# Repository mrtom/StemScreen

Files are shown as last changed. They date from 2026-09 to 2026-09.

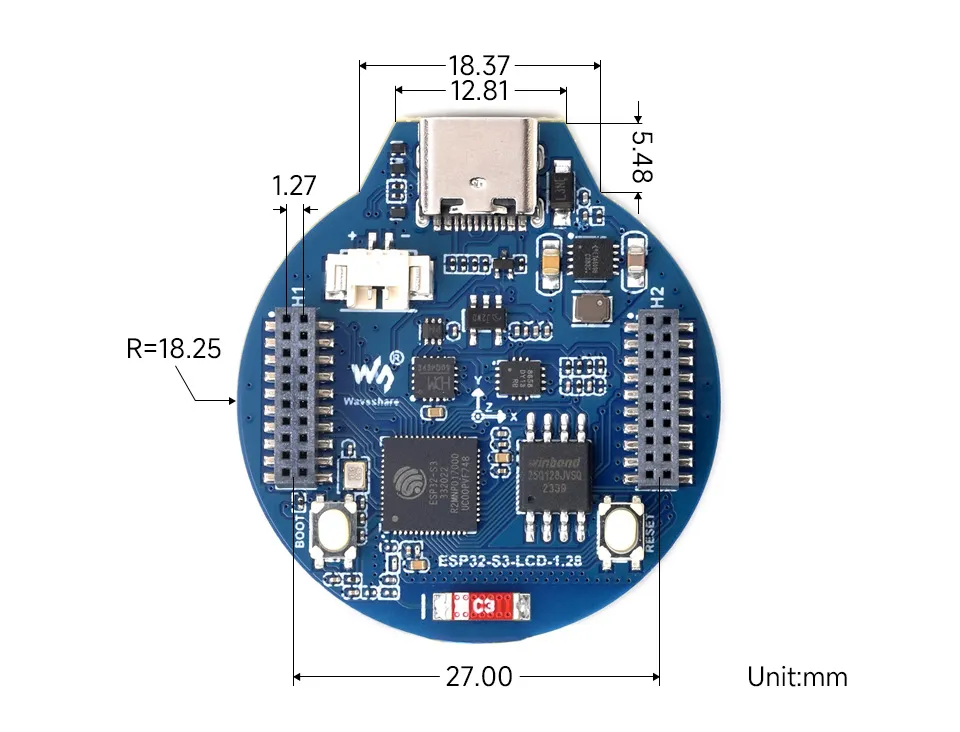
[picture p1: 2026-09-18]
CaseDesign/enclosure-v01/reference/waveshare-dimensions.webp

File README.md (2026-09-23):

# Bike Stem Computer — first Bluetooth test

## Display flicker fix (23 September 2026)

Text rectangles previously overwrote sections of the rings with black before
redrawing them, and the battery icon was cleared directly on the LCD. The new
renderer composes all layers in a 240×48 RAM buffer and sends each completed
band to the display. Unchanged screen/battery images are skipped. The buffer
uses 23,040 bytes (3,456 more than before); no full-screen allocation is needed.
The intended paused-status flash remains. Layout, battery levels and protocol
are unchanged. This addresses a concrete redraw issue; physical confirmation
that it resolves the reported flicker is pending.

Upload `StemScreen/StemScreen.ino` with the existing settings; no Garmin update
is needed. Check both pages for 30 seconds while running, including page rotation,
then pause: only the inner status ring should intentionally flash. The battery
icon and text should remain steady. If flicker persists, note the exact area and
whether it coincides with second ticks, page changes or pause flashing. Compare
USB-powered and battery-only operation with the same activity state. Flicker only
during updates suggests display scan/transfer tearing; whole-display brightness
changes or resets warrant a power/backlight investigation. Neither alternative
is established by the current report.

## Battery ring (22 September 2026)

The receiver now samples GPIO1 (`BAT_ADC`) with `analogReadMilliVolts()`: 16
readings spaced at least 10 ms apart, followed by a five-second interval. Sampling,
drawing and logging run outside BLE callbacks. `StemScreen/Battery.h` contains
the divider factor and the approximate LiPo interpolation curve (3.45 V empty,
4.20 V full). This is a voltage estimate, not a fuel gauge or runtime prediction.
Load, temperature and USB charging affect the estimate; 500 mAh does not change
the voltage curve.

Both rings are four pixels thick, separated by a two-pixel gap. A small battery
outline is centred on the battery ring at 12 o'clock on both pages, with two
pixels of black padding around it, and uses the battery ring colour. The icon is
empty at low, quarter/half/three-quarter filled at 25/50/75%, and solid at 100%.
Its fill uses the same stable level as the ring; invalid readings show an empty
grey icon. The outer battery ring appears outside the connection ring.
It fills clockwise from 12 o'clock, with small gaps at the quarter boundaries:

| Estimated charge | Outer ring |
| --- | --- |
| Below 25% | Short 15-degree red arc (low) |
| 25–49% | One quarter |
| 50–74% | Two quarters |
| 75–99% | Three quarters |
| 100% | Four quarters |

Non-low segments use the steady connection/activity tint, independent of paused
activity flashing. A two-percentage-point falling margin prevents rapid changes
at quarter boundaries. Invalid voltage or startup before sampling gives a grey
outline instead of a misleading full battery.

**Charging animation is implemented but not enabled on this board.** The
[non-touch schematic](https://files.waveshare.com/wiki/ESP32-S3-LCD-1.28/Esp32-s3-lcd-.128-sch.pdf)
does not show a charger-status or USB-present GPIO connection to the ESP32.
Firmware therefore reports `power=unknown`; high/rising voltage and an open
Serial Monitor are not charging detectors. A future reliable power-status input
can select `BatteryPower::Charging`: solid charge segments plus the next quarter
flashing every 500 ms, red below 25%, blue from 25% to below 100%, and the whole
ring flashing green at 100%. No hardware modification is part of this change.

**Verify the divider before relying on the ring.** Waveshare's
[current documentation](https://docs.waveshare.com/ESP32-S3-LCD-1.28) specifies
200 kΩ/100 kΩ (×3), whereas its linked schematic labels R4/R7 as 100 kΩ/100 kΩ
(×2). The implementation follows the requested ×3, exposed as `BATTERY_DIVIDER`.
ADC attenuation is 11 dB to accommodate either input range. Converted readings
outside 2.5–4.35 V are treated as invalid, not clamped to a full battery.

Upload `StemScreen/StemScreen.ino` using the existing ESP32S3/16MB/QSPI PSRAM
settings. This change needs no Garmin update if protocol v3 is already installed.
Open Serial Monitor at **115200 baud** and record `BAT t=... adc_mV=...
battery_mV=... approx_pct=... quarters=... valid=... power=unknown` lines.
Compare the connector voltage measured with a meter against `adc_mV` before
adjusting `BATTERY_DIVIDER`; record whether USB was connected. Check the ring on
both pages and during Garmin pause/stale/disconnected states. For a real discharge
runtime test, unplug USB-C (which supplies power/charges the cell), note start/end
times and ring transitions. USB serial logging itself changes the power conditions;
a battery-only serial capture needs an independently powered 3.3 V UART receiver
connected to board TX/GND only, with no power feed to the board. Do not infer
battery-only runtime from a USB-connected log. Physical calibration and runtime
validation are still pending.

Host battery checks:

```sh
c++ -std=c++11 -Wall -Wextra -Werror -pedantic tests/battery_test.cpp -o /tmp/stem-battery-test
/tmp/stem-battery-test
```

## Current display colours (22 September 2026)

The current clock/ride-time UI uses blue for fresh Garmin data with no activity
(or unknown activity state), and green for a confirmed activity. Running is steady
green; manual pause and Auto Pause flash the circumference ring green for 0.5 seconds,
then black for 0.5 seconds. The connection text and selected page dot share the
status colour but do not flash. Cyan means connected and awaiting data, orange
means no valid packet for five seconds, and red means disconnected. These link
warnings override activity colours and flashing. Time and detail text stay white
with fresh data and grey otherwise.

While running, a continuous local millisecond timer drives the ride display.
Garmin packets include fractional milliseconds. Packet arrivals preserve the local
phase: differences up to 150 ms are ignored; three consecutive larger differences
in the same direction trigger gradual correction at at most 1% of timer speed.
Pause/resume, timer resets, reconnection, recovery after stale data and differences
of at least two seconds resynchronise immediately. The number redraws as soon as
the main loop observes its next second, without waiting for the 250 ms UI refresh.
Paused, inactive or unknown activity states do not advance. Stale (five seconds),
disconnected and awaiting-data states show the last confirmed duration in grey.
BLE delivery delay is not measured, so this is a smooth estimate between samples.

**Update both devices for protocol v3.** Upload `StemScreen/StemScreen.ino` with
your existing ESP32S3 settings. Build `Garmin/monkey.jungle` for Edge 530 with your
developer key, copy the resulting `.prg` into the Garmin's `GARMIN/APPS`, replacing
the previous StemScreen app, eject and unplug. Version 1/2 packets are rejected;
an old sender/receiver combination will not provide live data after only one side
is updated. UUIDs and Garmin application ID are unchanged.

The counter setup notes below describe the earlier diagnostic version.

This sends a counter from your **Garmin Edge 530** to your **Waveshare ESP32-S3-LCD-1.28 non-touch** board, roughly once a second. The board only displays values it actually receives.

The aim is to prove that the connection works and keeps updating when you switch the Garmin to its map page. The clock, ride timer and rotating pages will come back in the next version. This counter is **not ride time**: it increments whenever Garmin calls the field's compute function, including while the activity timer is paused.

You will upload two programs: an Arduino sketch to the Waveshare, then a Connect IQ data field to the Garmin. There is no phone app or internet connection in the data path.

## 1. Upload the Waveshare program

1. Unzip this download. Keep the folder contents together.
2. Open **StemScreen/StemScreen.ino** in Arduino IDE. You should also see **BleProtocol.h** and **ReceiverState.h** tabs automatically.
3. Plug in the Waveshare. Use **ESP32S3 Dev Module** and the USB port that worked previously (your last port was `/dev/cu.usbmodem5ABA0067551`; the suffix can change).
4. Keep your working board settings. For reference: flash **16MB**, partition **16M Flash (3MB APP/9.9MB FATFS)**, PSRAM **QSPI PSRAM**, USB CDC On Boot **Disabled**, upload speed **115200**.
5. This sketch uses the same **Adafruit GC9A01A** and **Adafruit GFX** libraries as before. BLE comes with Espressif's board package; you do not need to install a separate Bluetooth library. It targets **esp32 by Espressif Systems 3.3.0**, selectable in Boards Manager.
6. Click **Upload**. After it completes, press the board's RESET/RUN button once if necessary.

**Expected result:** the round screen says **STEM RX d2**, **WAITING**, and `--`. That is correct until the Garmin program connects. You can leave the board plugged into your Mac for power.

If uploading stalls, use the same recovery sequence as before: hold BOOT, press and release RESET/RUN, release BOOT, then upload. Press RESET/RUN after upload. If the display is black, check the selected sketch and the Serial Monitor at **115200 baud**.

The original standalone clock/timer is included under **StandaloneBackup/StemScreen**. To restore it, open its `StemScreen.ino` and upload it. Keep the sketch inside its matching folder.

## 2. Set up Garmin development on your Mac

The Garmin source is included, but **there is no ready-to-copy Edge 530 PRG in this download**. Garmin requires sign-in to download its device definitions; I could run a general compiler check here but could not perform the final Edge 530 build. The following setup gets those definitions onto your Mac.

1. Install [Visual Studio Code](https://code.visualstudio.com/download) if you do not already have it.
2. Download the Mac **Connect IQ SDK Manager** from [Garmin's SDK page](https://developer.garmin.com/connect-iq/sdk/). Open it and sign in with your Garmin account.
3. In its **SDK** tab, install a stable SDK and make it active with **Use as SDK**. The source was checked with SDK **8.1.0**; you can select that version to match, or use a newer stable SDK.
4. In **Devices**, find **Edge 530** and download its device definition. Wait for the download to finish. This step is essential even though you physically own an Edge 530.
5. In VS Code's Extensions view, install **Monkey C**, published by **Garmin**. [Direct extension link](https://marketplace.visualstudio.com/items?itemName=garmin.monkey-c).
6. Press **Cmd–Shift–P**, run **Monkey C: Verify Installation**, and resolve any requirements it reports. If Java is missing, install a JDK supported by the extension; Java 17 was used for the general compiler check here. Restart VS Code after installing Java.
7. Press **Cmd–Shift–P** again and run **Monkey C: Generate a Developer Key**. Save the key somewhere you will retain, outside the downloaded project. This is the local signing key for your builds.

Garmin's [getting-started guide](https://developer.garmin.com/connect-iq/connect-iq-basics/getting-started/) covers the tools and key setup.

## 3. Build and copy the Garmin data field

1. In VS Code choose **File → Open Folder**, then select the **Garmin** folder in this download. You should see `manifest.xml`, `monkey.jungle`, `source` and `resources` in the sidebar. Open that folder itself, rather than an individual source file.
2. Plug your **Edge 530** into the Mac using a USB data cable. It should appear in Finder as a mounted Garmin drive. The Waveshare can remain connected separately.
3. Press **Cmd–Shift–P**, choose **Monkey C: Build for Device**, and select **Edge 530**. Choose an output folder on your Mac, such as a new `StemBuild` folder in Documents.
4. When the build finishes successfully, find its **.prg** file in that output folder. The exact filename is chosen by the build wizard/project.
5. In Finder, copy that `.prg` into **GARMIN/APPS** on the Edge. Copy the file itself, not the source folder or ZIP.
6. Eject the Garmin in Finder, then unplug its USB cable. Allow it to return to normal operation; restart it if the new field is not listed.

This is Garmin's supported [side-loading workflow](https://developer.garmin.com/connect-iq/connect-iq-basics/your-first-app/). There is no Connect IQ Store submission involved.

If Edge 530 is missing from the build menu, return to SDK Manager and confirm its definition is installed. If the build fails, copy the first error and the lines around it from VS Code's Output panel.

## 4. Put the field on a Garmin data page

On the Edge 530:

1. Go to **Menu → Settings → Activity Profiles**, then choose the cycling profile you will use.
2. Open **Data Screens → Add New → Data Screen**.
3. Select the **Connect IQ** category and **Stem BLE**. Finish with a layout containing just this one field, so its diagnostics are easy to read.
4. Return to that profile's ride screens and open the new page.

Garmin documents the screen setup in its [Edge 530 manual](https://www8.garmin.com/manuals/webhelp/edge530/EN-US/GUID-58CCEE56-34BF-44F4-ACCF-B81F6D716CA9.html).

**Do not use Add Sensor or your Mac's Bluetooth pairing screen.** The data field itself finds and connects to the board. For the first test, have one BikeStem board powered and keep it within a metre of the Garmin. Add this field only once to the active profile.

**Expected result:** Garmin progresses through **Searching → Connecting → Sending**. The Waveshare changes to **LIVE** and displays a growing number. Allow about 30 seconds for initial discovery.

The Garmin's large number counts compute calls, including calls before connection. It therefore need not begin at 1 on the board. **ACK** is the last counter acknowledged by the Bluetooth write operation; the Waveshare screen confirms the payload was decoded. A one-tick difference between screens is normal.

## 5. Run the useful tests

Start a short test activity while stationary. If Auto Pause intervenes, note that separately or temporarily disable it for this test.

| Test | What to look for |
| --- | --- |
| Leave Stem BLE visible for 30 seconds | Board stays LIVE and its received counter keeps increasing. |
| Switch the Garmin to its map page for 60 seconds | Board remains LIVE and its counter continues increasing. The view flag may stay set. |
| Return to the data field | Updates continue. Do not use the view flag as proof of the selected page. |
| Pause the Garmin activity timer | This diagnostic counter should continue; it is not yet the activity timer. |
| Unplug the Waveshare, wait 10 seconds, reconnect power | Board starts at WAITING; the Garmin should reconnect and resume updates. Allow up to 45 seconds. |
| Power off the Garmin while leaving the board powered | Board stops changing the number and shows STALE or WAITING. It must not invent further counts. |
| Restart Garmin and re-enter the profile's ride screens | Connection should resume; the Garmin counter may restart because the field was reloaded. |

Stopping or saving the activity, leaving its profile, or sleeping the Garmin is different from switching data pages. Continuous transmission occurs while the field remains loaded and Garmin continues calling it. Tom verified updates with the map visible for 120 seconds and WAITING/LIVE recovery after Garmin power-off/restart; see BUILD-NOTES.md for the exact observations and remaining checks.

You can discard the test activity afterwards. Once the map-page test works, we can replace the counter with Garmin's actual ride timer, pause state and time of day.

## Understanding the Waveshare screen

| Display | Meaning |
| --- | --- |
| WAITING | No BLE connection. Any number shown is an old value. |
| WAIT DATA | A central has connected, but no valid packet has arrived on this connection. |
| LIVE | A valid packet arrived within the last five seconds. |
| STALE | Connected, but no valid packet for at least five seconds. |
| Received … ago | Age of the last accepted packet. It increases when transmissions stop. |

The `View flag: set/clear` label comes from the last packet's onShow/onHide flag
(older installed builds say `Garmin page: visible/hidden`). It does not reliably
track selected data pages on Edge 530: the flag stayed set during the map test.
Clear is also its initial value before any onShow callback. When data is not live,
the label is replaced with a waiting/last-value message.

## If something does not work

- **Garmin stays at Starting:** install the current diagnostic build, identified
  by `Stem BLE diag2` on a full-height field. After 30 seconds report its exact
  status, P/S/A/Match/ACK values and your Edge firmware version. P is the profile
  result (0 = success); S is the scan callback state; A counts advertisement
  results, and Match counts results advertising our service (not unique devices).
  Scanning now starts independently of the registration callback; pairing still
  requires confirmed registration success. `No profile reply` means no registration
  callback arrived within 10 compute ticks; `Profile UUID?` means a callback
  arrived with an unexpected UUID; `Profile <number>` means registration failed.
  These registration diagnostics concern the Garmin's local BLE setup, not the
  receiver's packet decoder. Diag2 can scan while waiting for registration and
  still accepts a late success reply. `P:0 S:off` with `Sending` and increasing
  ACK is expected: registration succeeded and scanning stopped after selecting
  the board. Confirm LIVE on the Waveshare to verify packet decoding as well.
- **Board says WAITING; Garmin says Searching:** confirm the BLE sketch is uploaded, the field is open in your active profile, and both devices are nearby. A phone BLE scanner connected to the board can occupy the connection; disconnect it. Restart the board, then re-enter the Garmin profile.
- **Board says WAITING; Garmin says Sending with increasing ACK:** check whether
  ACK stops when this board is powered off. Upload the current receiver sketch
  (`STEM RX d2` heading), then capture startup and 30 seconds of Serial Monitor
  output at 115200. `BLE t=...` lines expose connect/disconnect and write counts,
  accepted/rejected packets, malformed packets, writes while marked disconnected,
  and last packet length. Raw GATTS connection/disconnection counts are included.
  RX d2 accepts valid writes even when onConnect was missed; malformed writes
  never refresh freshness. ACK alone does not confirm decoding on this board.
- **Board says WAIT DATA or STALE:** open Arduino Serial Monitor at **115200**. Accepted packets print `RX counter=… page=…`. Send me those lines and the Garmin status/ACK value.
- **Garmin shows IQ! or crashes:** connect it to the Mac and look in `GARMIN/APPS/LOGS` for `CIQ_LOG.YML` or `CIQ_LOG.TXT`. Share the relevant error entry, plus your Garmin firmware and SDK versions.
- **Works on the data page, stops on the map:** leave the board powered and note whether it shows STALE or WAITING. Confirm the field still exists in the same active profile. This is precisely the hardware behaviour this prototype is designed to test.
- **PRG copied but field absent:** check it is in `GARMIN/APPS`, was built for Edge 530, and that the device was ejected/unplugged. Restart Garmin and check the Connect IQ data-field category again.

Please report the visible-page result, map-page result, and power-cycle reconnection result. Those three observations will tell us whether the link is ready for real ride data.

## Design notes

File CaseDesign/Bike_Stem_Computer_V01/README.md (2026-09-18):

# Bike Stem Computer — V01 printable fit prototype

The editable master is **Bike_Stem_Computer_V01.f3d**. It contains the Fusion timeline, 54 named user parameters, separate components, and Waveshare's official STEP reference. The STEP export is for interchange; the F3D retains the editable feature history. Dimensions are millimetres.

## Size and construction

- Round body: **54.5 mm diameter × 22.5 mm high**; **28.8 mm** including the replaceable mount. The temporary side cap increases overall width to approximately 55.7 mm.
- The 35 × 30 mm rectangular battery, its corner clearance, and the sealing land determine the diameter.
- Top bezel: 33.2 mm viewing aperture, underside seat for a **38 mm diameter × 1 mm polycarbonate lens**, 0.25 mm radial lens clearance and 0.5 mm clearance above the LCD.
- Lower shell: flat 4.2 mm floor, battery rails with 0.7 mm side clearance, 0.5 mm soft pad allowance and 0.9 mm nominal clearance above the battery.
- Removable 1 mm carrier separates the cell from the electronics. Three posts support the PCB underside; three peripheral locators limit sideways movement. Three soft rim pad references occupy the gap between the inactive LCD rim and the lens. Use compliant material and avoid loading the active display.
- Three underside M2 screws capture the carrier and engage heat-set inserts in the upper shell. The case opens without disturbing the replaceable underside mount.
- Shell seam: continuous groove for a **50 mm ID × 1.5 mm cross-section silicone O-ring**, 1.8 mm wide and 1.2 mm deep (nominal 20% squeeze). This is a prototype gland, not a tested ingress rating.
- USB-C opening: **13 × 6 mm** cable tunnel aligned to the official USB connector model. A **16.6 × 8 mm** outer recess reserves room for a future TPU plug flange. The plug itself is not included.
- Power control: generic **6 mm side opening**, plus a separate blanking cap. It is a mechanical provision, not an installed switch or power circuit. Select the switch before finalising its internal clearance and retention. BOOT and RESET remain accessible when the case is opened; neither is treated as a power switch.
- Mount: separate male quarter-turn fit-test cartridge, fastened with two M2 screws on a custom **24 mm pitch** into blind holes in the base. The flange/neck/ears are parameterised. Its ear dimensions are provisional and are not a published Garmin specification. Test insertion, turning, retention and clearance on the intended female mount; alter or replace only this component as needed.

## Printing

Use the five STL files in **print/**. They have been rotated onto their intended printing faces and placed at Z=0. The STL files in the main folder retain assembly coordinates.

| Part | Suggested first print | Orientation / support |
|---|---|---|
| 01 Bottom shell | PETG, 0.2 mm layers, 4 perimeters | Flat underside on bed; cavity up |
| 02 Top shell and bezel | PETG, 0.2 mm layers, 4 perimeters | Bezel face on bed; inspect USB bridge in slicer |
| 03 Removable electronics carrier | PETG, 0.2 mm layers | Flat separator face on bed; posts up |
| 04 Replaceable quarter turn cartridge | PETG fit coupon first, dense/solid | Flange on bed; local support under projecting ears if required |
| 07 Switch blanking cap | TPU fit trial | Flange on bed; stem up |

Use printer-specific compensation only after measuring a fit print. Keep supports off sealing faces, insert bores and the lens seat where possible. The short carrier locators are delicate; remove the carrier by its broad tabs. The polycarbonate lens and silicone O-ring are purchased/cut parts, not ordinary opaque prints.

## Assembly items and sequence

1. Dry-fit the empty shells, carrier, USB cable and mount cartridge. Confirm the actual battery pack including protection board, pouch seams, connector and cable fits without bending or compression. Pi Hut's published size is described as the cell size.
2. Fit three M2 heat-set inserts into the top shell and two into the base. **3.2 mm bore × 3.2 mm depth is a starting allowance**: match the actual insert supplier and test in spare material before installation.
3. Bond the clear lens into the underside bezel seat using a continuous compatible flexible seal. The model includes the cover but no adhesive solid. Protect the optical area from adhesive.
4. Use a thin soft pad to hold the battery on the floor. Route its cable around the cell and through the carrier's rear-left relief. Keep leads away from screw bosses and the O-ring.
5. Place the board on the carrier's three supports. Use small removable compliant pads to prevent rattling; confirm they bear only on clear PCB / inactive display rim regions. The reference geometry is not a substitute for inspecting the delivered board revision.
6. Install the O-ring, carrier and lid. Start with three **M2 × 12 mm** case screws and thin sealing washers under the heads; check actual engagement and shorten if necessary. Do not force the screws into a blind bore. Recesses are 4.2 mm diameter × 1.8 mm deep.
7. Fit the mount cartridge using two **M2 × 4 mm** screws. Check head fit and remaining insert depth. The 1.5 mm head recesses suit low-profile heads; change the recess parameter for the selected hardware.
8. Temporarily seal the blanking cap with removable compatible sealant. It is not a validated press-fit seal. Make the TPU USB plug and selected switch sealing arrangement before rain use. Seal the case-screw paths with the under-head washers/sealant as required.

First evaluate fit and sealing without electronics. This version has no claimed IP rating and is not yet validated for riding. The mount should pass physical retention testing before carrying the computer on a bike.

## Editing

Use Fusion's Change Parameters. The principal groups are `battery_*`, `pcb_*`, `case_*`, `lens_*`, `seal_*`, `usb_*`, `switch_*`, `insert_*` and `mount_*`. The enclosure geometry and Z stack use expressions. The official imported Waveshare assembly is a static reference placed at **screen_z = 20 mm**: move that reference to the new `screen_z` after changing the vertical stack. The nominal battery and lens reference bodies update parametrically.

Changing the battery footprint substantially also requires checking `cavity_diameter`, screw positions, battery rails and seal dimensions. Parameters support iterative changes, not arbitrary combinations. The seal centre is intentionally independently adjustable for a purchased O-ring.

## Verification performed

- Native Fusion features recompute without timeline errors or warnings.
- Every printable component contains one solid body.
- Pairwise solid-intersection checks found no overlaps between the printable parts, cover lens, nominal battery, or official assembled Waveshare geometry.
- `pcb_clearance` changed from 0.4 to 0.6 mm and restored: no timeline errors or warnings.
- All five exported STL meshes are closed two-manifold surfaces with one connected shell. Their millimetre dimensions and print heights were checked.
- These checks do not establish print tolerance, switch suitability, fastener strength, mount engagement, water resistance or battery-pack manufacturing tolerances.

## Dimension sources

- [Waveshare ESP32-S3-LCD-1.28 documentation](https://docs.waveshare.com/ESP32-S3-LCD-1.28): 32.4 mm active display and non-touch board identification.
- [Waveshare official mechanical package](https://files.waveshare.com/wiki/ESP32-S3-LCD-1.28/ESP32-S3-LCD-1.28.zip): 36.5 mm PCB width, 39.5 mm overall length; imported STEP gives 7.9 mm full rear depth and USB location. Local originals are under reference/.
- [Pi Hut 500 mAh PicoBlade battery, SKU 106602](https://thepihut.com/products/500mah-3-7v-lipo-battery-1-25mm-picoblade-connector): 35 × 30 × 5 mm nominal cell, 3.7 V, approximately 100 mm lead.

The enclosure and mount geometry are original prototype designs. The official Waveshare model is included as an attributed hardware reference.

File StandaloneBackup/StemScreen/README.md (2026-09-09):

# Bike Stem Computer - prototype 02

For the **Waveshare ESP32-S3-LCD-1.28 non-touch** board, using the same display pins and libraries as the working Hello/Ride Time sample.

## What it does

- Starts on a **24-hour clock** showing large hours/minutes and the date.
- Rotates between Clock and **Ride Time** every **10 seconds**.
- Ride Time uses **HH:MM:SS** and starts paused at zero.
- **Tap BOOT:** start, pause, or resume the ride timer. The action happens on release.
- **Hold BOOT for 2 seconds:** reset the timer to zero and leave it paused. The reset happens while held; releasing it does not start it again.
- Either button action immediately shows Ride Time and starts a fresh 30-second page interval.
- The timer continues while the clock page is visible. Clock adjustments cannot change the elapsed ride time.

A small pair of dots at the bottom shows which page is visible. Green means the timer is running; amber means paused. The display only redraws when its content changes, using a RAM buffer to avoid clearing flicker.

BOOT is the button to use during normal operation. RESET/RUN restarts the whole program. Holding BOOT while resetting or powering up still enters the ESP32's download mode; release BOOT and press RESET on its own to run normally.

## Upload the update

1. Close the old Arduino sketch window. Keep your edited original folder as a backup if you want it.
2. Unzip the new download. Move the complete **StemScreen** folder to your working location. It must contain both **WaveShare.ino** and **RideLogic.h**. Replace the old folder or use a separate parent directory; do not copy just the `.ino` file.
3. Open **StemScreen.ino** in Arduino IDE. The helper header should appear as another tab.
4. Keep the board settings that worked for Hello. Select your board port; at the time of setup it was **/dev/cu.usbmodem5ABA0067551** (the name can change).
5. Click Verify, then Upload. If needed, press RESET/RUN once after uploading.
6. You should see CLOCK. Tap BOOT to see Ride Time start counting. Tap again to pause; wait, tap again, and confirm it resumes. Hold for two seconds to clear it. Leave it alone for 30 seconds to see it switch pages.

No extra libraries or hardware are required.

## Setting the clock

**On every startup this sample seeds its clock with the date/time embedded when the sketch was compiled on your Mac.** This is convenient for an initial demo but is only an approximation: compilation and uploading take time. An old/cached build or a restart later will reuse an old time. The screen labels this **Approx time - set via USB**.

The compiler timestamp is interpreted as **UK local time**, assuming the Mac used for compilation is also on UK time. The display uses GMT/BST automatically. If the Mac is on another timezone, use the USB command below to set it correctly.

To set it from your Mac after uploading (or after a restart):

1. Open **Tools > Serial Monitor** on the board's port.
2. Choose **115200 baud** and the **Newline** line-ending option. Opening a serial connection can reset some boards; wait for it to be ready before sending.
3. In your Mac's Terminal, run:

   ```bash
   printf 'TIME %s\n' "$(date +%s)"
   ```

4. Copy the resulting line, for example `TIME 1788888888`, straight into the Serial Monitor input and press Send/Enter. **Use the number generated by your Mac, not the example number.**
5. The board replies `OK: clock set from USB. Ride timer unchanged.` and prints its current local time. When the clock page is visible it says **Time set from Mac**.

Copy/paste introduces a few seconds of delay, so this is sufficient for the prototype's minute display, not a precision time synchronisation method. Run the Terminal command again if you leave a gap before sending it. The command uses Unix time, so it works regardless of your Mac's timezone; the screen converts to UK time.

You can also send `STATUS` to print the clock, elapsed time, and running/paused state. Use Newline or Both NL & CR. Invalid or oversized commands are rejected.

**Resetting, uploading, or removing power clears the ride timer and this sample's clock sync.** After restarting, it returns to the embedded build time and the approximate-time label. This sample intentionally does not save an old clock value as if it were current. Later, the Garmin connection can supply live time and ride state.

## Change the screen interval or orientation

Near the top of `StemScreen.ino`:

```cpp
constexpr uint64_t SCREEN_INTERVAL_MS = 30000;
constexpr uint8_t DISPLAY_ROTATION = 0;
```

Use `15000` for 15-second page rotation. Keep the interval greater than zero. Use rotation `0`, `1`, `2`, or `3`. Save and upload again.

The UK timezone is configured with `TIME_ZONE`. The timer itself uses a 64-bit monotonic counter, independent of time-of-day and daylight-saving changes. Its on-screen value saturates at 99:59:59 instead of wrapping to zero; this is a prototype limitation for very long activities.

## Environment reference

| Component | Version |
| --- | --- |
| Desktop editor | Arduino IDE 2 |
| esp32 by Espressif Systems | 3.3.0 |
| Adafruit GC9A01A | 1.1.1 |
| Adafruit GFX Library | 1.12.6 |
| Adafruit BusIO | 1.17.4 |

Install board support with Arduino's Boards Manager. If needed, the additional board-manager URL is:

```text
https://espressif.github.io/arduino-esp32/package_esp32_index.json
```

Install the libraries through Library Manager, accepting dependencies. No TFT_eSPI or LVGL configuration is needed.

| Tools setting | Value |
| --- | --- |
| Board | ESP32S3 Dev Module |
| Upload Speed | 115200 |
| CPU Frequency | 240MHz (WiFi) |
| Flash Mode | QIO 80MHz |
| Flash Size | 16MB (128Mb) |
| Partition Scheme | 16M Flash (3MB APP/9.9MB FATFS) |
| PSRAM | QSPI PSRAM |
| USB Mode | Hardware CDC and JTAG |
| USB CDC On Boot | Disabled |
| Upload Mode | UART0 / Hardware CDC |
| USB Firmware MSC On Boot / USB DFU On Boot, if shown | Disabled |
| Erase All Flash Before Sketch Upload | Disabled |

Other options can stay at defaults. The board's USB-C uses a CH343 serial bridge; keep USB CDC On Boot disabled so `Serial` uses that connection.

The unchanged internal display connections are SCK=10, MOSI=11, CS=9, DC=8, RESET=12, backlight=40. BOOT uses GPIO 0 with an active-low input. These are already wired on the PCB.

## Troubleshooting

- **RideLogic.h missing:** keep the complete sketch folder together.
- **Upload cannot connect:** close Serial Monitor, hold BOOT, tap RESET/RUN, release BOOT, then Upload. After success, release BOOT and tap RESET/RUN again.
- **BOOT appears not to work:** short presses act on release; long presses need two seconds. Use BOOT, not RESET/RUN. A button held during boot enters download mode rather than operating this app.
- **No port:** compare `ls /dev/cu.*` before and after plugging in. `ioreg -p IOUSB -w0` shows USB devices. On your macOS 26.5.2, `system_profiler SPUSBDataType` produced no output, so use `ioreg` instead. Your existing serial port already worked; no new driver is needed.
- **Blank Serial Monitor:** check the port, 115200 baud, and USB CDC On Boot = Disabled; press RESET/RUN for startup messages.
- **No reply to TIME:** choose Newline in Serial Monitor and send the generated command without quotes/backticks.
- **Clock wrong after a restart:** set it again with TIME. Build time is only a fallback, not a battery-backed clock.

## Code and validation

`StemScreen.ino` handles the display, wall clock, serial commands and input polling. `RideLogic.h` contains the timer, debounced button logic, elapsed-time formatting and time-command validation, keeping these separate from the future BLE transport.

`tests/test_logic.cpp` is a small native C++ test of pause/resume/reset, minute/hour formatting, long-press release behaviour, bounce rejection, a counter crossing the 32-bit millisecond boundary, invalid time commands and text fitting inside the circular screen. Arduino does not build this tests folder. Developers can run it with:

```bash
c++ -std=c++11 -Wall -Wextra -Werror tests/test_logic.cpp -o /tmp/bike-logic-test
/tmp/bike-logic-test
```

The updated sketch compiled successfully with Arduino-ESP32 3.3.0 and the library versions/settings above: 411,991 bytes of flash and 22,640 bytes of global variables (plus a 115,200-byte display buffer allocated on the heap). All native logic checks passed.

The previous Hello sample was confirmed working on Tom's board. This update still requires physical verification of the clock, button handling and page rotation; automated checks do not replace that hardware check.

Sources: [Waveshare schematic](https://files.waveshare.com/wiki/ESP32-S3-LCD-1.28/Esp32-s3-lcd-.128-sch.pdf), [Adafruit display library](https://github.com/adafruit/Adafruit_GC9A01A), [Espressif time APIs](https://docs.espressif.com/projects/esp-idf/en/stable/esp32s3/api-reference/system/system_time.html).

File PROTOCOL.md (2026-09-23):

# Ride protocol v3

The Garmin Edge 530 is the BLE central/GATT client; StemScreen is the peripheral.
BLE local name: `BikeStem`. Discovery matches the service UUID, not the name.

- Service: `93e1b4a0-5c21-4e62-a738-9d608c17f201`
- RX characteristic: `93e1b4a1-5c21-4e62-a738-9d608c17f201`
- Operation: write with response, exactly 20 bytes, unsigned little-endian integers.
- Garmin application ID: `9080770dece64c76b104c84a44d0bad1` (unchanged).

| Offset | Bytes | Value |
| --- | --- | --- |
| 0 | 2 | Magic `42 53` hexadecimal (ASCII BS) |
| 2 | 1 | Version 3 |
| 3 | 1 | Kind 2: ride snapshot |
| 4 | 1 | Validity flags: bit 0 clock, bit 1 duration, bit 2 activity state |
| 5 | 1 | State: 0 Off, 1 manually stopped, 2 Auto Paused, 3 Running |
| 6 | 2 | Garmin local year (2000–2099) |
| 8 | 1 | Month (1–12) |
| 9 | 1 | Day (validated against month/year) |
| 10 | 1 | Hour (0–23) |
| 11 | 1 | Minute (0–59) |
| 12 | 1 | Second (0–59) |
| 13 | 1 | Reserved zero |
| 14 | 4 | Whole active ride seconds, from Garmin `timerTime` |
| 18 | 2 | Fractional active ride milliseconds (0–999) |

Flags outside bits 0–2, unknown states, invalid dates/times, nonzero reserved bytes,
and fractions above 999 are rejected. Fields whose validity flag is clear must
be zero, including both duration components. Unknown state is distinct from a
valid Off state. No timezone conversion is needed: the clock fields are local.

Version 2 used the same layout but reserved bytes 18–19 as zero and discarded
fractional time. Version 1 was a 16-byte diagnostic counter. The current receiver
rejects both old versions. **Deploy sender and receiver together**; the version
bump prevents an incompatible pair from silently interpreting the new fields.

## Timer display and freshness

The receiver records `millis()` only for accepted packets. A fresh Running state
with valid duration and state enables a continuous millisecond estimate, driven
by the board's monotonic clock. New running packets preserve its fractional phase.
Errors within 150 ms are ignored. Three consecutive errors outside that deadband
in the same direction enable rate correction, limited to 10 ms per second (1%).
This suppresses isolated arrival jitter and avoids backwards steps during normal
correction. State changes, decreasing source duration, a gap of at least five
seconds, reconnects and errors of at least two seconds resynchronise immediately.
The source fraction is retained without increasing the BLE payload beyond 20 bytes.

Garmin snapshot time and BLE delivery delay are not separately measured; the
estimate can lag Garmin by transport latency. Paused/off/unknown states do not
advance. After disconnection or five seconds without a valid packet, the display
uses the last confirmed duration in grey. Rendering never refreshes packet age
or changes the confirmed packet. A new connection requires fresh data before
local advancement resumes. Arithmetic handles `millis()` wrap and saturates the
displayed duration at the wire seconds maximum instead of overflowing.

## Transport and lifecycle

`compute()` samples and transmits independently of rendering. The sender keeps
at most one write in flight, sending the latest snapshot rather than queuing old
values. Five compute ticks without acknowledgement trigger a connection reset;
disconnected handles get about 25 ticks before rediscovery, followed by a retry
delay of three ticks. These are compute ticks, not wall-clock timeouts.

Startup submits the profile then starts scanning independently of registration's
callback; waiting for that callback before scanning stalled on Tom's Edge 530.
Pairing/writes still require successful registration. Scanning stops after a
matching peripheral is selected. `onShow`/`onHide` are view lifecycle diagnostics,
not dependable page visibility or activity state; they never gate transmission.

A valid write is connection evidence even if `onConnect` is absent. Invalid
writes never change freshness or the clock estimate. Server callbacks and the
custom Bluedroid GATTS hook handle disconnects; duplicate connect events preserve
fresh data. Missing disconnect events still lead to STALE after five seconds.
The cause of previously missing callbacks on core 3.3.11 remains unestablished.

Callbacks decode/copy state and perform bounded clock arithmetic under a short
lock. All display and serial work remains in the main loop. The 240×48 display band
buffer uses 23,040 bytes; all overlapping layers are composed before transfer. The prototype uses no authentication/bonding and selects
the first matching service. A write acknowledgement proves transport completion,
not successful packet decoding; receiver output is the acceptance evidence.

## Local battery display

Battery sensing and the outer ring are receiver-local. No battery percentage or
charging flag is transmitted over BLE; the v3 packet and Garmin sender are unchanged.
See README.md for voltage calibration and the unavailable charging-status signal.

## Host checks

```sh
c++ -std=c++11 -Wall -Wextra -Werror -pedantic tests/protocol_test.cpp -o /tmp/stem-protocol-test
/tmp/stem-protocol-test
c++ -std=c++11 -Wall -Wextra -Werror -pedantic tests/ride_clock_test.cpp -o /tmp/stem-ride-clock-test
/tmp/stem-ride-clock-test
```

Garmin encoding tests are in `Garmin/tests/RideDataTest.mc`, built with
`Garmin/tests.jungle` and `monkeyc -t`, then executed in the Edge 530 simulator.

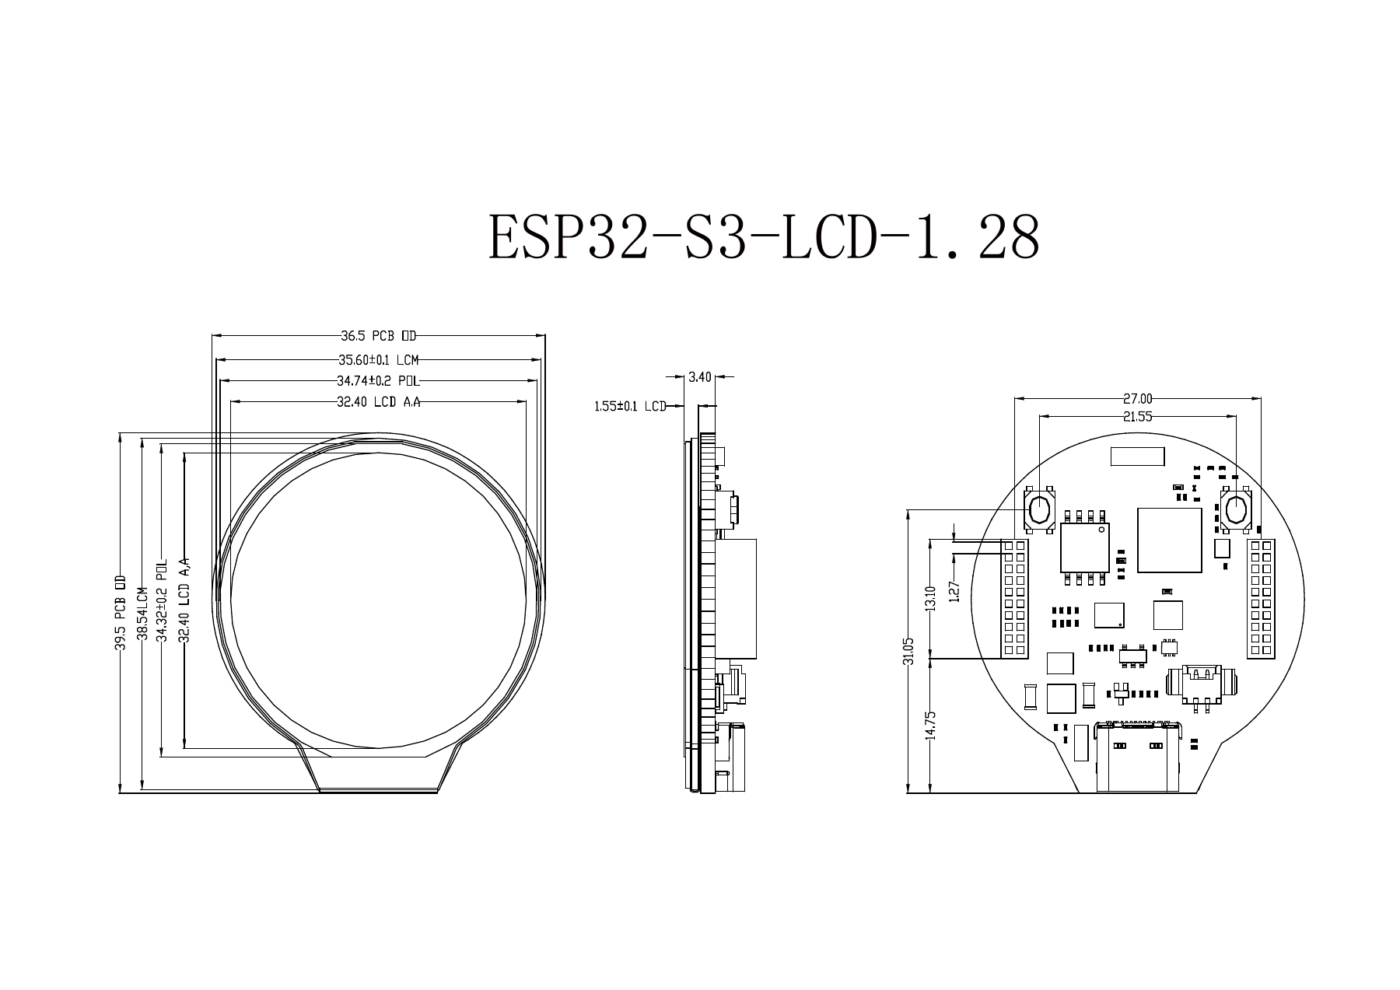
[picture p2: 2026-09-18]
CaseDesign/enclosure-v01/reference/drawing.png

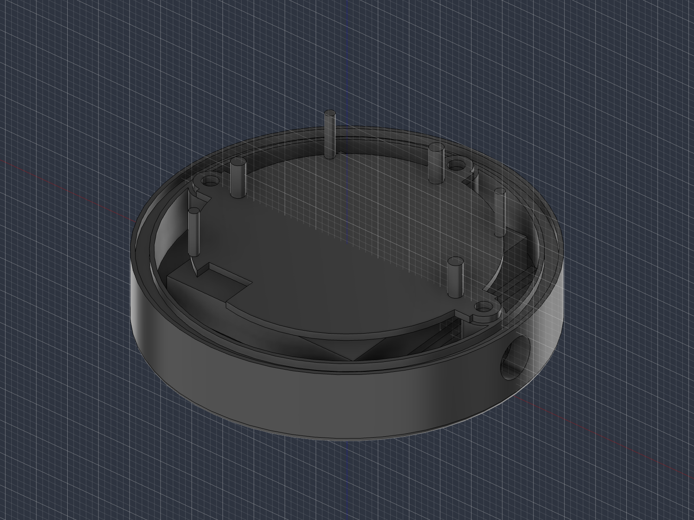
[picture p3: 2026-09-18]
CaseDesign/Bike_Stem_Computer_V01/internal-preview.png

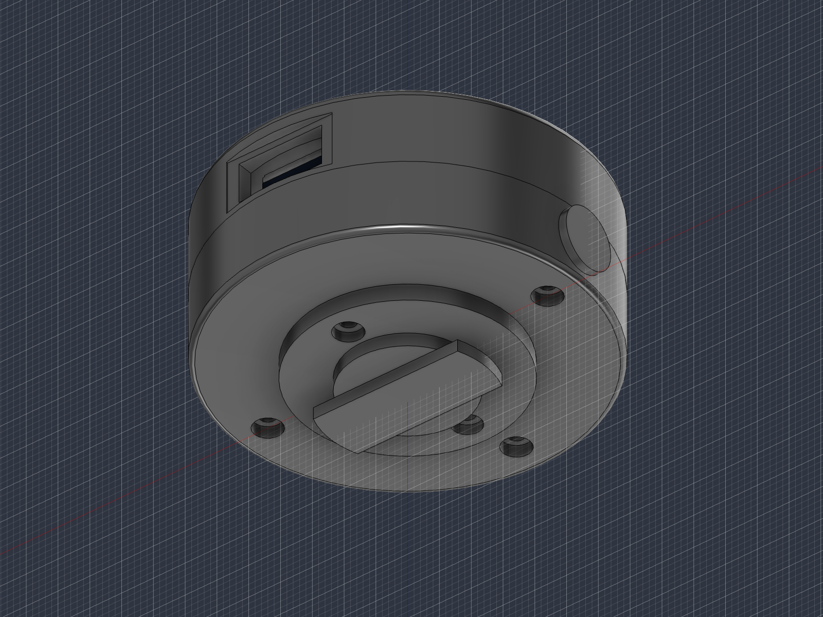
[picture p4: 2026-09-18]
CaseDesign/Bike_Stem_Computer_V01/underside-preview.png

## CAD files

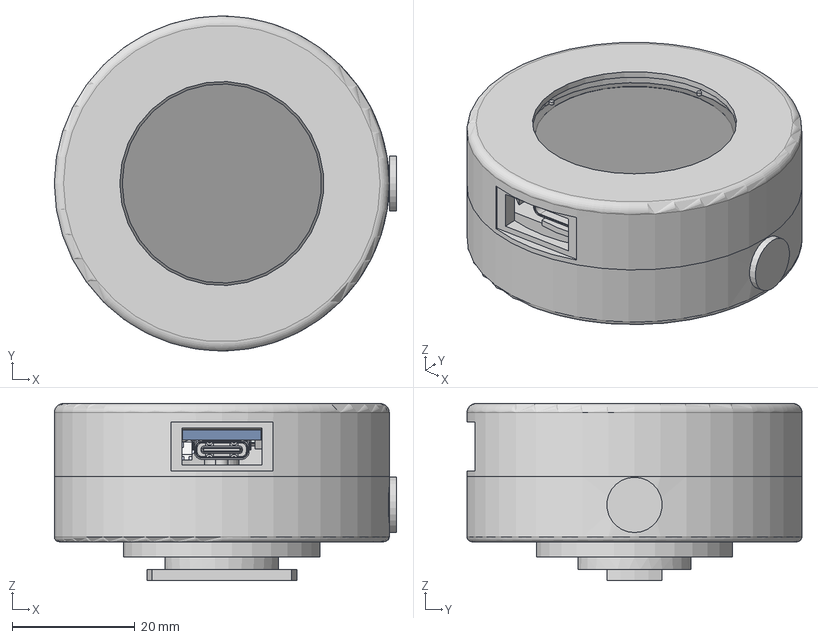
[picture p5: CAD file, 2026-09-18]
CaseDesign/Bike_Stem_Computer_V01/Bike_Stem_Computer_V01.step
55.7 x 54.5 x 28.8 mm
1_28INCH-240X240-TFT
BOARD
USER_LIBRARY-RES_0603-0201_1 x 16
USER_LIBRARY-RES_0603-0201_2 x 16
USER_LIBRARY-RES_0603-0201_3 x 16
USER_LIBRARY-RES_0603-0201_4 x 16
EXTRUDED-16000
EXTRUDED-16701
EXTRUDED-17152 x 2
USER_LIBRARY-0201_0603M__CAP_1 x 23
USER_LIBRARY-0201_0603M__CAP_2 x 23
USER_LIBRARY-0201_0603M__CAP_3 x 23
EXTRUDED-28486
SW3DPS-SOT-23-5-DEFAULT
EXTRUDED-34339
EXTRUDED-221459
EXTRUDED-221831
EXTRUDED-222203
EXTRUDED-222575
EXTRUDED-223534
3_1_A x 3
EXTRUDED-260467 x 2
EXTRUDED-260839 x 4
LEGS_SEITE_2
LEGS_SEITE_1
EXTRUDED-271125
EXTRUDED-271544
EXTRUDED-271916 x 6
L0201_1 x 2
L0201_2 x 2
L0201_3 x 2
HP1_25MMX2PIN-SMT
BUTTON-3X4X2_5MM-SMT x 2
ESP32-S3-CORE
C3-001

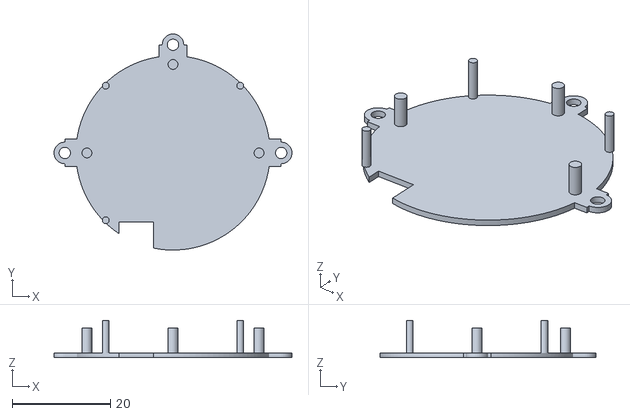
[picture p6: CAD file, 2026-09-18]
CaseDesign/Bike_Stem_Computer_V01/print/03_Removable_electronics_carrier.stl
48.4 x 43.9 x 7.60

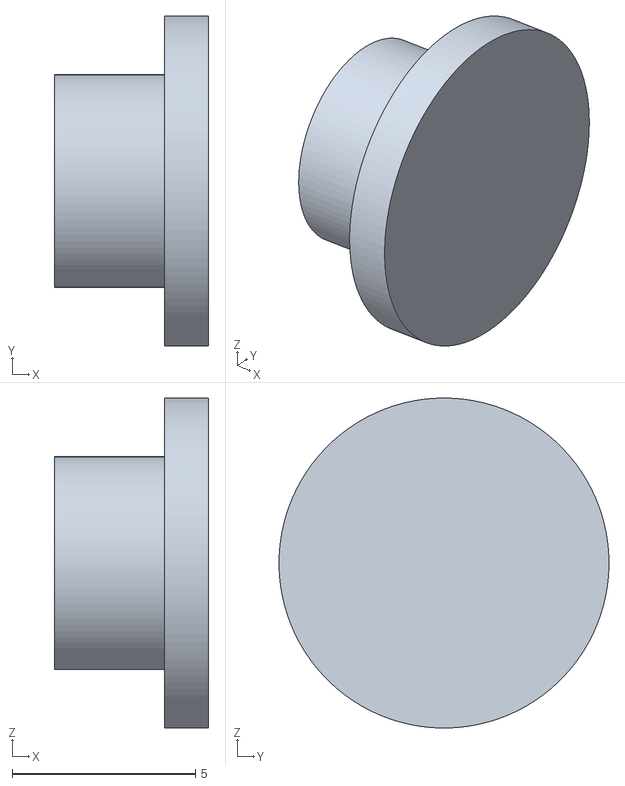
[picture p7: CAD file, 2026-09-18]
CaseDesign/enclosure-v01/07_Switch_blanking_cap.stl
4.20 x 9.00 x 9.00

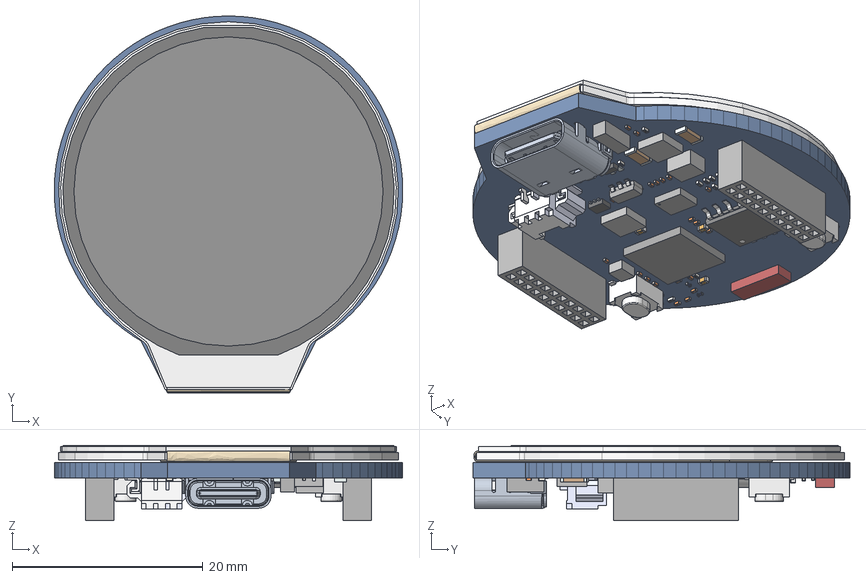
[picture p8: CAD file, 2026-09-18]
CaseDesign/enclosure-v01/reference/ESP32-S3-LCD-1.28/ESP32-S3-LCD-1_28.stp
36.5 x 39.5 x 7.90 mm
1_28INCH-240X240-TFT
BOARD
USER_LIBRARY-RES_0603-0201_1 x 16
USER_LIBRARY-RES_0603-0201_2 x 16
USER_LIBRARY-RES_0603-0201_3 x 16
USER_LIBRARY-RES_0603-0201_4 x 16
EXTRUDED-16000
EXTRUDED-16701
EXTRUDED-17152 x 2
USER_LIBRARY-0201_0603M__CAP_1 x 23
USER_LIBRARY-0201_0603M__CAP_2 x 23
USER_LIBRARY-0201_0603M__CAP_3 x 23
EXTRUDED-28486
SW3DPS-SOT-23-5-DEFAULT
EXTRUDED-34339
EXTRUDED-221459
EXTRUDED-221831
EXTRUDED-222203
EXTRUDED-222575
EXTRUDED-223534
3_1_A x 3
EXTRUDED-260467 x 2
EXTRUDED-260839 x 4
LEGS_SEITE_2
LEGS_SEITE_1
EXTRUDED-271125
EXTRUDED-271544
EXTRUDED-271916 x 6
L0201_1 x 2
L0201_2 x 2
L0201_3 x 2
HP1_25MMX2PIN-SMT
BUTTON-3X4X2_5MM-SMT x 2
ESP32-S3-CORE
C3-001

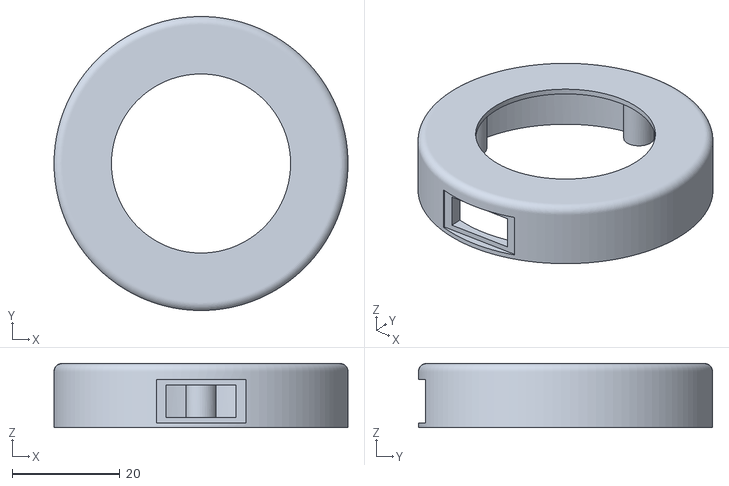
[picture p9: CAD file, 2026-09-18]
CaseDesign/enclosure-v01/02_Top_shell_and_bezel.stl
54.5 x 54.5 x 11.9

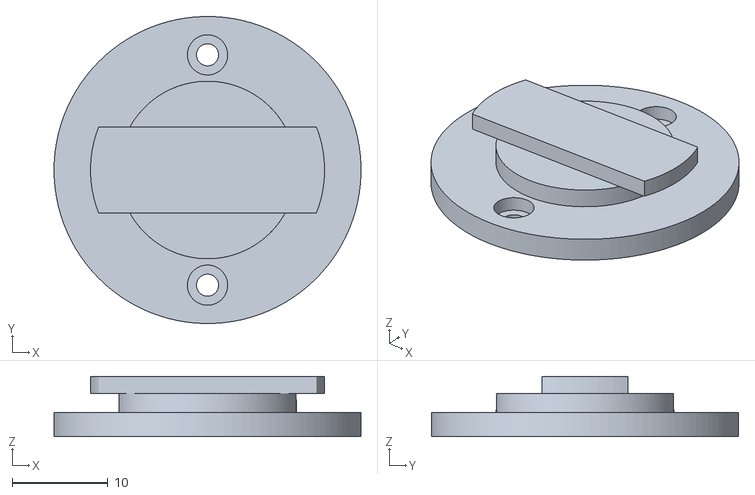
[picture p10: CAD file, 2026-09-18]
CaseDesign/Bike_Stem_Computer_V01/print/04_Replaceable_quarter_turn_cartridge.stl
32.0 x 32.0 x 6.30

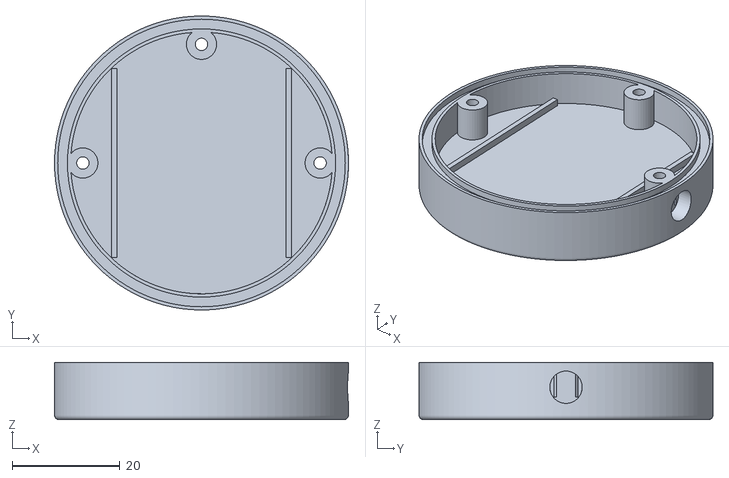
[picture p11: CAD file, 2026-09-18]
CaseDesign/Bike_Stem_Computer_V01/print/01_Bottom_shell.stl
54.5 x 54.5 x 10.6

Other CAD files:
CaseDesign/Bike_Stem_Computer_V01/print/07_Switch_blanking_cap.stl
CaseDesign/enclosure-v01/reference/ESP32-S3-LCD-1.28/ESP32-S3-LCD-1.28.dwg
CaseDesign/Bike_Stem_Computer_V01/print/02_Top_shell_and_bezel.stl
CaseDesign/enclosure-v01/04_Replaceable_quarter_turn_cartridge.stl
CaseDesign/enclosure-v01/03_Removable_electronics_carrier.stl
CaseDesign/enclosure-v01/01_Bottom_shell.stl
CaseDesign/Bike_Stem_Computer_V01/Bike_Stem_Computer_V01.f3d
CaseDesign/enclosure-v01/Bike_Stem_Computer_V01.f3d
CaseDesign/enclosure-v01/print/02_Top_shell_and_bezel.stl
CaseDesign/enclosure-v01/print/07_Switch_blanking_cap.stl

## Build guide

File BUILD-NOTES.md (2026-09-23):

# Validation

## Local display flicker — 23 September 2026

Tom reports portions of the display repeatedly flicking off/on rather than a
whole-screen backlight flash. Source inspection found a concrete mechanism:
every 250 ms, black-backed text strips overwrote overlapping circle pixels,
then the rings were restored via individual draw operations. The battery icon
also received a direct black clear before repaint. This is the leading software
explanation, not a hardware-confirmed diagnosis.

Added `DisplayRenderer.h` to compose all overlapping elements into full-width
240×48 bands offscreen and transfer only completed bands. Repeated identical
screen/battery images skip LCD writes. All layout, icon levels and deliberate
pause flashing remain; all rendering stays outside BLE locks. The canvas grows
from 19,584 to 23,040 bytes (+3,456); no full-frame allocation is used on-device.
This is not a panel-synchronised atomic frame swap; scan tearing may still need
investigation if symptoms remain after upload.

Validation:

- Receiver compile passed with installed ESP32 core 3.3.11 and existing board
  settings: 652,135 bytes program storage, 30,204 bytes globals (canvas heap
  allocation excluded). Output: `/tmp/stem-render-build`.
- New renderer regression uses the actual installed Adafruit_GFX canvas with
  minimal host Arduino shims: every pixel in five bands matches a complete-frame
  reference across both pages, all battery levels, invalid readings and flashing
  phases. Checks include icon padding, ring/text overlap and redraw comparisons.
- Existing battery, protocol/UI/receiver and continuous-clock suites passed with
  C++11 and warnings treated as errors. `git diff --check` passed.
- No upload, hardware confirmation, Garmin rebuild or simulator run performed.
  Garmin and the BLE packet format are unchanged.

Next: upload the receiver; watch both pages while running for at least 30 seconds,
including rotation and second ticks, then pause (only the status ring should
flash). If local flicker persists, record its location/cadence and compare USB
versus battery under the same state. Update-only artifacts suggest scan tearing;
brightness changes/resets suggest investigating power/backlight separately.

## Battery icon fill levels — 22 September 2026

The top battery icon now follows the ring's stable quarter level: empty for low,
quarter/half/three-quarter interior fill for 25/50/75%, and a solid body for 100%.
Invalid readings remain an empty grey outline. Its position, two-pixel padding
and colour remain unchanged. The backing clears previous fills on each redraw,
so falling levels leave no old pixels. Sensing and BLE behaviour are unchanged.
Receiver compilation passed with ESP32 core 3.3.11: 651,471 bytes program
storage, 30,028 bytes globals. `git diff --check` passed. No new host tests were
needed for this drawing-only change. No upload or Garmin/simulator run performed.
Physical appearance still needs checking on the receiver after upload.

## Battery icon centred on ring — 22 September 2026

Moved the battery outline onto the outer stroke at 12 o'clock, with a black
backing providing two pixels of clear padding on every side. Both four-pixel
rings move inward three pixels (battery radii 112–115, status 106–109), preserving
the two-pixel gap while fitting the icon and padding within the round display.
The eight-pixel-high icon and battery stroke share vertical centre y=6.5.
Backing is drawn after both rings so they cannot overwrite its padding.
Receiver compilation passed with ESP32 core 3.3.11: 651,419 bytes program
storage, 30,028 bytes globals. `git diff --check` passed. No upload performed.
Hardware appearance remains unverified; check the top icon and both rotating
pages after uploading the receiver. Garmin, battery sensing and timing unchanged.

## Thicker rings and battery icon — 22 September 2026

Both rings now use four-pixel strokes, retaining a two-pixel gap: battery radii
115–118 and connection/status radii 109–112. A small battery outline is centred
at 12 o'clock inside the rings on both pages, using the steady battery colour.
No sensing, charging detection, BLE or timing behaviour changed.

Receiver compilation passed with ESP32 core 3.3.11 and the existing board
settings: 651,403 bytes program storage and 30,028 bytes globals.
`git diff --check` passed. No upload was performed. No new host tests were
needed for this drawing-only change; Garmin and simulator checks were not run.

Physical appearance remains unverified; upload the receiver and check ring
separation, icon legibility and both rotating pages.

## Battery sensing and outer ring — 22 September 2026

Tom reports a 500 mAh 3.7 V LiPo is now connected. Added GPIO1 calibrated-millivolt
sampling (16 spaced samples per batch, five-second batch interval), configurable
×3 divider, nonlinear LiPo interpolation, range validation and quarter-level
hysteresis. The outer two-pixel ring starts clockwise from 12 o'clock: low below
25% is a 15-degree red arc; the other levels are 25/50/75/100% quarters using the
steady link/activity tint. It appears on both pages without changing ride timing.

Waveshare's current non-touch documentation specifies ×3, but its linked schematic
labels R4/R7 as 100k/100k (×2). Meter calibration on this board is required. The
schematic provides no documented charger-status/USB-present connection to ESP32;
power remains Unknown. Charging animation rules are implemented and host-tested
but cannot activate automatically on the stock board. No voltage-trend or USB
serial heuristic is used. See README for sources, calibration and logging.

Validation:

- Battery, protocol/UI/receiver and continuous-clock host suites all passed with
  C++11 and `-Wall -Wextra -Werror -pedantic`. Battery checks cover curve points,
  interpolation, clamping/monotonicity, divider conversion, invalid readings,
  quarter hysteresis, charging animation/colours, averaging and scheduler rollover.
- Receiver compile passed with installed ESP32 core 3.3.11 and documented board
  settings: 651,435 bytes program storage, 30,028 bytes globals. Build output:
  `/tmp/stem-battery-build`.
- Garmin source and protocol unchanged; no Garmin build or simulator run needed
  or performed. No upload, physical ADC calibration, display inspection, charging
  detection or runtime test was performed. `git diff --check` passed.

Next: upload the receiver with existing Arduino settings. Capture BAT serial lines
at 115200 and compare ADC voltage to a meter at the cell connector to settle the
divider. Check both pages, pause flashing and link loss, then unplug USB for a
battery-only runtime test. USB-connected logs are not a discharge runtime test.

## Continuous ride clock and protocol v3 — 22 September 2026

Tom reports the first interpolation improved gaps but still produced uneven
seconds. That implementation discarded Garmin's fractional seconds and restarted
the local phase at every packet. Protocol v3 preserves the millisecond remainder
in bytes 18–19 of the existing 20-byte packet; v1/v2 are rejected, so both devices
must be updated together. UUIDs and the Garmin app ID remain unchanged.

`RideClock.h` now preserves a continuous local estimate. It ignores errors within
150 ms and requires three consecutive larger errors in the same direction before
correcting at up to 1% of timer speed. Pause/resume, source timer regression,
stale recovery/reconnection and discrepancies of at least two seconds synchronise
immediately. Stale/disconnected views still show the last confirmed value in grey.
The ride number redraws when its second changes, independently of the general
250 ms refresh. BLE delivery latency remains unmeasured; this is an estimate.

Validation:

- Both host suites passed with C++11, `-Wall -Wextra -Werror -pedantic`.
  Coverage includes v3 fractions/invalid values/old-version rejection, exact
  one-second ticks over irregular packet arrivals and three-second gaps, positive
  and negative drift convergence without jumps, alternating jitter, state changes,
  resets, stale/reconnect recovery, malformed data, millis rollover and overflow.
- Receiver compilation passed with ESP32 core 3.3.11 and the documented board
  settings: 636,367 bytes program storage and 29,756 bytes globals. Output:
  `/tmp/stem-continuous-clock-build`.
- Production and test builds passed for Edge 530 using Connect IQ SDK 9.2.0.
  The existing 32×32-to-35×35 icon scaling warning remains. Java compilation needed
  `JDK_JAVA_OPTIONS=-Djava.awt.headless=true` after the normal launcher aborted
  while initialising macOS AWT. Production output: `/tmp/stem-continuous-clock.prg`;
  test output: `/tmp/stem-continuous-clock-tests.prg`. The production PRG is also
  copied to ignored `Garmin/builds/continuous-clock/Garmin.prg` for sideloading.
- Simulator execution could not be completed: Launch Services returned -10827,
  and launching the installed simulator executable directly aborted (exit 134).
  Garmin tests compiled but were not executed. No physical upload/test performed.
- `git diff --check` passed.

Next: install the new Garmin PRG and upload the receiver. Check regular seconds
while running with two-to-three-second packet gaps, manual pause/Auto Pause,
resume, activity end/restart, and stale/disconnection recovery on both pages.
Compare against Garmin over a longer run; BLE delay and the selected correction
thresholds still need evaluation on the actual devices.

## Ride timer between packets — 22 September 2026

Tom reports the ride display looks stuck between Garmin packets. Rendering now
adds elapsed whole seconds from the existing `millis()` receive timestamp when
the last valid packet reports Running with a valid duration and activity state.
Each new packet replaces the anchor and duration, including downward corrections.
The Garmin packet remains unchanged; local rendering cannot refresh freshness.
Manual/Auto Pause, Off and unknown state never advance locally. At five seconds
without valid data, or on disconnection/reconnection awaiting data, the UI returns
to the last confirmed duration in grey. The Garmin sender still sends whole
seconds, so this smooths gaps without claiming subsecond Garmin accuracy.

Host tests passed with C++11 and warnings treated as errors: millisecond second
boundaries, a three-second packet gap, authoritative resync, malformed writes,
pause/resume/off/unknown states, missing duration, stale/disconnect/reconnect,
millis rollover and duration overflow. Receiver compilation passed with ESP32
core 3.3.11 and the documented board settings: 635,891 bytes program storage,
29,708 bytes globals. `git diff --check` passed. No Garmin build or simulator
run was needed/performed; the sender and wire format are unchanged. No upload
was performed and hardware validation is pending.

Next: upload the receiver with the existing Arduino settings. Verify that ride
time ticks during two-to-three-second packet gaps, stops after receiving manual
pause/Auto Pause, resumes correctly, and resynchronises after a gap. Verify grey
last-confirmed values after stale data or disconnect. No Garmin update is needed.

## Activity colours and paused ring — 22 September 2026

The current ride UI now uses blue for fresh data with no activity or unknown
activity state, steady green for running, and a green/black circumference ring
alternating every 500 ms for manual pause and Auto Pause. Connection text and
the active page dot retain the steady status tint. Cyan (awaiting data), orange
(stale) and red (disconnected) override activity state. Packet arrivals do not
restart flashing; the main loop redraws when the ring changes phase.

Host protocol/receiver/UI tests passed with C++11 and warnings treated as errors,
including both pause types on both pages, 500 ms boundaries, packet arrival during
the black phase, resume/no activity/unknown state, and link-warning precedence.
Receiver compilation passed with ESP32 core 3.3.11 and the documented board
settings: 635,831 bytes program storage and 29,708 bytes globals. Build output:
`/tmp/stem-activity-colours-build`. `git diff --check` passed.

Garmin source and packet format were unchanged; no Garmin build or simulator run
was performed. This receiver update has not been uploaded or physically tested.
Next: upload `StemScreen/StemScreen.ino` using the existing Arduino settings;
check blue before starting/after ending an activity, steady green while running,
500 ms green/500 ms black while manually paused and Auto Paused, and steady green
on resume. Check both clock and ride-time pages, steady text/dot during flashing,
and that stale/disconnection warnings still replace the activity colour.

## Map updates and Garmin restart verified — 17 September 2026

With Garmin diag2 and receiver RX diag2, Tom reports:

- Waveshare stayed LIVE and continued counting while the Garmin showed the map,
  for at least 120 seconds. Its page label nevertheless remained visible.
- Powering off Garmin changed Waveshare to WAITING and stopped the counter.
  Exact transition latency was not measured.
- Powering Garmin on immediately restored connection and LIVE, with the counter
  restarting from zero and the view flag initially hidden.
- Entering the activity profile set the flag to visible and reset the counter
  again. App/field recreation is consistent with this, but no lifecycle trace
  was captured to establish the exact instance sequence.

The main map-page transmission requirement and receiver recovery after Garmin
restart are now physically verified. The visible/hidden flag is not a dependable
page detector on this Edge firmware. Source display wording now says
`View flag: set/clear`; wire bytes and transport behavior are unchanged. No
additional upload is required to retain the working link.

The wording-only receiver update compiled successfully with core 3.3.11
(633,911 bytes program storage, 29,676 bytes globals); `git diff --check` passed.
This updated label has not been physically uploaded/tested in this session.

Remaining checks include RX diag2 LIVE recovery after cycling board power,
manual/Auto Pause behavior, and connected-but-silent STALE behavior on hardware.
The five-second freshness boundary is host-tested, but powering Garmin off
tested disconnection, not a silent connection. No ride-timer feature is implemented.

## Confirmed end-to-end LIVE — 17 September 2026

Tom reports RX diag2 displaying `STEM RX d2`, `LIVE`, counter `889`,
`Garmin page: Visible`, and `Received 0s ago`, with Garmin diag2 running on
Edge 530 software 9.75. This is the first confirmed receiver acceptance and
fresh display of a Garmin packet. RX diag2 was compiled for ESP32 core 3.3.11.

Two changes resolved the observed blockers: Garmin begins scanning after
submitting its profile without waiting for the registration callback; the
receiver accepts valid writes as connection evidence when onConnect is missed.
The underlying platform callback behavior remains unexplained. No further
firmware change is needed before the remaining bench tests.

Still to verify: counter progression and LIVE for 60 seconds with the Garmin
map visible (`Garmin page: hidden`), loss of LIVE within five seconds of the
last valid packet when Garmin is powered off, and reconnection with accepted
packets after power cycling either device. Garmin-side reconnect/ACK recovery
after board power cycling was already observed before RX diag2; receiver-side
LIVE recovery with the new firmware has not yet been reported.

## Receiver callback recovery — 17 September 2026

Tom's RX diag1 log identifies ESP32 core 3.3.11 and shows 29 valid 16-byte writes,
zero connect/disconnect callbacks, zero accepted packets, and 29 rejections
solely because the receiver's connected flag stayed false. Packet encoding and
arrival are verified; the exact cause of the missing callbacks is not established.

RX diag2 accepts a valid GATT write as connection evidence. It keeps validation
and the five-second freshness threshold, and adds the bundled Bluedroid library's
custom GATTS hook for connect/disconnect handling without replacing the library's
own ESP-IDF callback. State transitions are idempotent across duplicate/late
connection notifications. If no disconnect event arrives, silence still gives
STALE. Missing disconnect events and advertising recovery need physical testing.

Host tests passed with warnings treated as errors: valid writes without a connect
callback, malformed writes before/after connection, stale boundary, duplicate
events, disconnect/reconnect, pending advertising cancellation and millis rollover.
The pure state logic is in StemScreen/ReceiverState.h. Garmin diag2 is unchanged.
Receiver compilation passed with ESP32 core 3.3.11 and the documented board
settings: 633,895 bytes program storage and 29,676 bytes global variables.
Build artifacts are in `/tmp/stem-rx-diag2-build`; no upload has been performed
by Codex. `git diff --check` passed.
Next physical test: upload RX diag2, confirm LIVE and accepted/RX counters, then
stop Garmin transmission and verify it cannot remain LIVE after five seconds.

## Latest hardware result — 17 September 2026

Tom reports the following on Edge 530 software 9.75 with diag2 after 30 ticks:
`Sending`, `P:0 S:off A:1`, `Match 1 ACK 30`.
This verifies successful profile registration, discovery of the matching service,
connection and acknowledged GATT writes from the Garmin. Scanning is intentionally
off after selecting the peripheral. Starting scanning after submitting the profile,
without waiting for its callback, resolved the observed startup stall in this test.
The underlying Garmin callback scheduling behavior has not been established.

Tom subsequently reports the Waveshare still shows WAITING. End-to-end delivery
is therefore not verified. The Garmin ACK result does not establish that this
board's callbacks accepted the packets. Map-page testing is deferred until the
receiver shows LIVE.

Receiver diag1 adds a `STEM RX d1` heading, core version and BLE address at startup,
and main-loop serial diagnostics for connect/disconnect events, write count,
accepted/rejected packets, malformed writes, writes while marked disconnected,
and last write length. Counts are snapshotted under the existing short lock;
logging remains outside callbacks. A status line prints every five seconds and
on connection/rejection changes. No packet acceptance or connection logic changed.
Tom confirmed the board power-off test: Garmin changes to Reconnecting and ACK
stops when the Waveshare is unplugged; after restoring power, Sending and
incrementing ACK resume. This ties the observed link to this board and verifies
Garmin-side reconnection after board power cycling. Receiver acceptance remains
unverified because its screen still reports WAITING.

Receiver diag1 compiled successfully with installed ESP32 core 3.3.11 and the
documented ESP32S3/16MB/QSPI PSRAM settings: 633,863 bytes program storage and
29,668 bytes global variables (runtime allocations excluded). Build output is
in `/tmp/stem-rx-diag1-build`. It has not yet been uploaded or physically tested.
Next: upload receiver diag1 and capture startup plus 30 seconds of serial output
at 115200 with Garmin diag2 running. The physical cause remains unconfirmed.

## Hardware report — 17 September 2026

Tom reports successfully building and running both the standalone backup and
current StemScreen sketch on the Waveshare. He also successfully compiled and
installed the Garmin app on his Edge 530 and added the Connect IQ field to a data
screen. After starting an activity, the devices did not connect successfully.
BLE discovery, packet delivery, hidden-page updates and reconnection are not yet
verified. The earlier Edge build/sideload blocker is resolved.

Repository review found two commits: the standalone prototype (6c73c8c), followed
by the BLE prototype and preserved standalone backup (df2548c). Corrected stale
sketch paths in README and the protocol test include after the folder rename.
The installed local toolchains are ESP32 core 3.3.11 and Connect IQ SDK 9.2.0;
the versions used for the reported device builds have not yet been confirmed.
After the include correction, host protocol/freshness tests passed with
`c++ -std=c++11 -Wall -Wextra -pedantic`; `git diff --check` also passed.
No firmware rebuild, Garmin rebuild, simulator run or physical test was performed
during this initial review. Awaiting the exact statuses shown by both devices and
the receiver's startup serial output to locate the failing connection stage.

## Startup diagnostic — 17 September 2026

Tom observed an increasing Garmin counter (60), status `Starting`, ACK 0, and
Waveshare `WAITING`. After reset the board printed its ROM boot messages followed
by `BikeStem ready: waiting for the Garmin data field.` This locates the observed
stall before the Garmin's scan path; it does not establish successful advertising.

Added `Stem BLE diag1` identification, explicit registration status, callback
logging, visible UUID-mismatch reporting, and a `No profile reply` message after
10 compute ticks. A late successful callback can still advance to scanning.
No automatic re-registration or bypass of registration success was added.
The root cause remains unconfirmed; install this diagnostic build and report the
status after 15 seconds, plus Edge firmware version.

Edge 530-target compilation succeeded with local SDK 9.2.0 and the configured
developer key. The compiler warns that the existing 32x32 icon is scaled to
35x35. Output: `Garmin/builds/diagnostic/Garmin.prg` (ignored build artifact).
No simulator or physical test of this diagnostic version has been performed.

## Independent scan diagnostic — 17 September 2026

On Edge 530 software 9.75, Tom installed diag1 and observed `No profile reply`
and ACK 0 after 15 seconds. The device reports no software update available.
This confirms the registration-wait branch is reached, without proving a
firmware defect or determining why the callback is absent.

Diag2 starts scanning after registerProfile returns instead of waiting for its
callback. Garmin's bundled NordicThingy52 example likewise registers profiles
in onStart and initiates scanning separately without implementing
onProfileRegister. This is a startup experiment: StemScreen still requires a
successful matching registration callback before pairing or writing.

The full-height field displays P (profile result, 0 means success), S (scan
callback state), A (advertisement results), Match (matching service results),
and ACK. Advertisement counts are observations, not unique devices, and cap at
9999. A missing profile reply still gets a timeout message after 10 compute ticks.
No repeated profile registration is performed. Late success can enable pairing.

Diag2 compiled successfully for Edge 530 with SDK 9.2.0; only the existing icon
scaling warning remains. Simulator execution is untested. Subsequent physical
results are recorded at the top of this document.

## Historical validation — 9 September 2026

## Waveshare

Compiled successfully for ESP32S3 Dev Module using Espressif Arduino core 3.3.0, Adafruit GC9A01A 1.1.1, Adafruit GFX 1.12.6 and Adafruit BusIO 1.17.4.

Compiler report: 681,839 bytes of program storage out of 3,145,728; 34,440 bytes of global variables out of 327,680. These figures exclude runtime allocations by BLE and the display strip buffer; they are not measurements of free RAM on a running board.

Equivalent Arduino CLI command from this package's root, with the libraries/core already installed:

```sh
arduino-cli compile --fqbn 'esp32:esp32:esp32s3:FlashSize=16M,PartitionScheme=app3M_fat9M_16MB,PSRAM=enabled,FlashMode=qio,CDCOnBoot=default,USBMode=hwcdc,UploadMode=default,UploadSpeed=115200' StemScreen
```

## Garmin

Both source files and resources passed a general, device-independent compilation with Connect IQ SDK 8.1.0 and Java 17. This check used a temporary copy with an empty product list; its only final warning was that no supported devices were defined. The delivered manifest retains the correct `edge530` target.

**This is not an Edge 530 build or simulator run.** The official device-definition endpoint returned HTTP 401 because a Garmin login is required. Device-specific API availability, resource limits and on-device behaviour remain to be checked by the final build and hardware tests. No generic PRG is included because it is not an Edge 530 deliverable.

Use the README's Build for Device instructions. If using the CLI instead, with Garmin's SDK bin folder on PATH and Edge 530 definitions installed:

```sh
monkeyc -f Garmin/monkey.jungle -d edge530 -y /absolute/path/to/your/developer_key.der -o StemBLE.prg -w
```

## Packet tests

The host C++ test passed: fixed wire bytes/endian decoding, short/long/null input rejection, invalid headers/flags/reserved-byte rejection, five-second freshness boundary, disconnected/new-connection state, and millisecond counter wrap.

Run from this package's root:

```sh
c++ -std=c++11 -Wall -Wextra -pedantic tests/protocol_test.cpp -o /tmp/stem-protocol-test
/tmp/stem-protocol-test
```

No physical Waveshare or Edge was available here. BLE discovery, timing, screen appearance, hidden-page updates, and reconnection require the bench tests in README.md. The included standalone backup was preserved from the previous prototype; it was not modified for BLE.

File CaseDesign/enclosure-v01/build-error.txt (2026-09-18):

Traceback (most recent call last):
  File "/Users/tom/.codex/.chatgpt-projects/g-p-6a9d8d1c1284819184e1e62b811bf19b/enclosure-v01/BikeStemEnclosure/BikeStemEnclosure.py", line 135, in run
    disk(bottom,'Outer lower shell','case_diameter','0 mm','seam_z')
    ~~~~^^^^^^^^^^^^^^^^^^^^^^^^^^^^^^^^^^^^^^^^^^^^^^^^^^^^^^^^^^^^
  File "/Users/tom/.codex/.chatgpt-projects/g-p-6a9d8d1c1284819184e1e62b811bf19b/enclosure-v01/BikeStemEnclosure/BikeStemEnclosure.py", line 53, in disk
    s=sketch(c,name,z);circle(s,dia,x,y);return extr(c,s,depth,op,name)
                       ~~~~~~^^^^^^^^^^^
  File "/Users/tom/.codex/.chatgpt-projects/g-p-6a9d8d1c1284819184e1e62b811bf19b/enclosure-v01/BikeStemEnclosure/BikeStemEnclosure.py", line 35, in circle
    s.sketchDimensions.addDiameterDimension(e,pt(x,y)).parameter.expression=dia
    ~~~~~~~~~~~~~~~~~~~~~~~~~~~~~~~~~~~~~~~^^^^^^^^^^^
  File "/Users/tom/Library/Application Support/Autodesk/webdeploy/production/4fcc3ec853a7fe76514fe04cc5fd7741e6b2c4ff/Autodesk Fusion.app/Contents/Api/Python/packages/adsk/fusion.py", line 70603, in addDiameterDimension
    return _fusion.SketchDimensions_addDiameterDimension(self, entity, textPoint, isDriving)
           ~~~~~~~~~~~~~~~~~~~~~~~~~~~~~~~~~~~~~~~~~~~~~^^^^^^^^^^^^^^^^^^^^^^^^^^^^^^^^^^^^
RuntimeError: 3 : Some input argument is invalid.

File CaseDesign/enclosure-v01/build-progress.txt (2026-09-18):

Starting native Fusion build
Bottom completed
Top completed
Carrier completed
Mount completed
Validating and exporting
SUCCESS - local F3D, STEP and print meshes exported

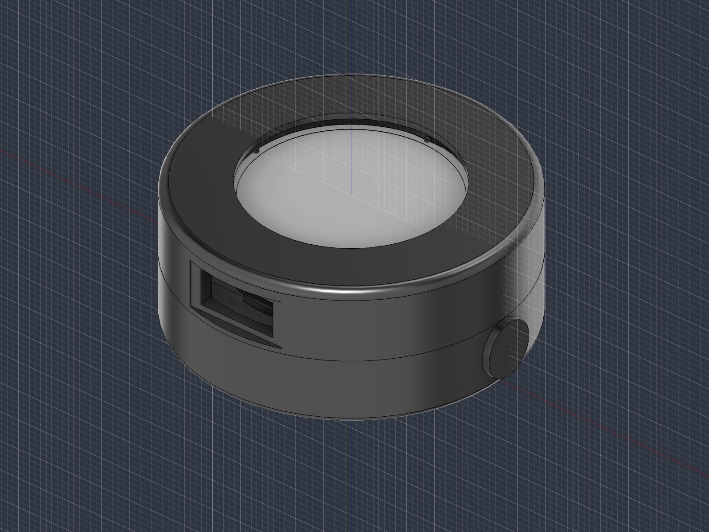
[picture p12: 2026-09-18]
CaseDesign/Bike_Stem_Computer_V01/assembled-preview.png

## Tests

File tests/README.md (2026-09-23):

# Host checks

Run the dependency-free suites from the repository root:

```sh
for suite in battery protocol ride_clock; do
  c++ -std=c++11 -Wall -Wextra -Werror -pedantic "tests/${suite}_test.cpp" -o "/tmp/stem-${suite}-test" && "/tmp/stem-${suite}-test" || exit 1
done
```

The rendering regression uses your installed Adafruit_GFX library (the same
library used by the firmware). Set its directory for your Arduino installation:

```sh
GFX_LIBRARY_DIR="$HOME/Documents/Arduino/libraries/Adafruit_GFX_Library"
c++ -std=c++11 -Wall -Wextra -Werror -pedantic -DARDUINO=100 \
  -Itests/gfx_host -I"$GFX_LIBRARY_DIR" tests/display_renderer_test.cpp \
  "$GFX_LIBRARY_DIR/Adafruit_GFX.cpp" -o /tmp/stem-display-test
/tmp/stem-display-test
```

`gfx_host` supplies only the Arduino compatibility needed by RAM canvas drawing;
it does not simulate SPI, LCD scan timing or hardware. The test compares all band
pixels to a complete offscreen frame and checks overlapping layers, icon padding,
flashing states and visible-change detection. Hardware flicker still needs a
physical check after upload.

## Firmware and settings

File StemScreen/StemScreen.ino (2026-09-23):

// StemScreen ride UI: Garmin local clock and active activity timer.
// Waveshare ESP32-S3-LCD-1.28 NON-TOUCH; Arduino ESP32 core 3.3.0.
#include <Arduino.h>
#include <SPI.h>
#include <Adafruit_GFX.h>
#include <Adafruit_GC9A01A.h>
#include <BLEDevice.h>
#include <BLEServer.h>
#include <BLEUtils.h>
#include <esp_arduino_version.h>
#include "RideUi.h"
#include "Battery.h"
#include "DisplayRenderer.h"

#if !defined(CONFIG_IDF_TARGET_ESP32S3)
#error "Select ESP32S3 Dev Module"
#endif
SPIClass displaySPI(HSPI);
Adafruit_GC9A01A display(&displaySPI, 8, 9, 12);
// One full-width band composes all overlapping layers before LCD transfer.
GFXcanvas16 strip(DISPLAY_WIDTH, DISPLAY_BAND_HEIGHT);
PageRotation rotation;
constexpr int STEM_BATTERY_PIN = 1;
BatteryState battery;
BatterySampler batterySampler;

portMUX_TYPE stateLock = portMUX_INITIALIZER_UNLOCKED;
ReceiverState sharedState;

class ServerEvents : public BLEServerCallbacks {
  void onConnect(BLEServer*) override {
    portENTER_CRITICAL(&stateLock);
    ++sharedState.connects;
    sharedState.connectionOpened();
    portEXIT_CRITICAL(&stateLock);
  }
  void onDisconnect(BLEServer*) override {
    portENTER_CRITICAL(&stateLock);
    ++sharedState.disconnects;
    sharedState.connectionClosed();
    portEXIT_CRITICAL(&stateLock);
  }
};
class WriteEvents : public BLECharacteristicCallbacks {
  void onWrite(BLECharacteristic* characteristic) override {
    const auto value = characteristic->getValue();
    const uint32_t now = millis();
    portENTER_CRITICAL(&stateLock);
    sharedState.receive(reinterpret_cast<const uint8_t*>(value.c_str()), value.length(), now);
    portEXIT_CRITICAL(&stateLock);
  }
};
ServerEvents serverEvents;
WriteEvents writeEvents;

#if defined(CONFIG_BLUEDROID_ENABLED)
// Use the library's hook; do not replace its ESP-IDF callback registration.
void receiverGattEvent(esp_gatts_cb_event_t event, esp_gatt_if_t, esp_ble_gatts_cb_param_t*) {
  if (event != ESP_GATTS_CONNECT_EVT && event != ESP_GATTS_DISCONNECT_EVT) { return; }
  portENTER_CRITICAL(&stateLock);
  if (event == ESP_GATTS_CONNECT_EVT) {
    ++sharedState.rawConnects;
    sharedState.connectionOpened();
  } else {
    ++sharedState.rawDisconnects;
    sharedState.connectionClosed();
  }
  portEXIT_CRITICAL(&stateLock);
}
#endif

void drawScreen(const RideScreen& screen, uint32_t now) {
  static bool drawn = false;
  static RideScreen previousScreen;
  static BatteryState previousBattery;
  static BatteryRing previousRing;
  const BatteryRing ring = batteryRing(battery, screen.tint, now);
  if (drawn && sameScreen(screen, previousScreen) &&
      sameBatteryImage(battery, ring, previousBattery, previousRing)) return;
  for (int y = 0; y < DISPLAY_HEIGHT; y += DISPLAY_BAND_HEIGHT) {
    composeBand(strip, y, screen, battery, ring);
    display.drawRGBBitmap(0, y, strip.getBuffer(), DISPLAY_WIDTH, DISPLAY_BAND_HEIGHT);
  }
  previousScreen = screen;
  previousBattery = battery;
  previousRing = ring;
  drawn = true;
}
void setup() {
  Serial.begin(115200);
  pinMode(STEM_BATTERY_PIN, INPUT);
  // Covers both the documented /3 input and /2 on older schematic revisions.
  analogSetPinAttenuation(STEM_BATTERY_PIN, ADC_11db);
  pinMode(40, OUTPUT); digitalWrite(40, LOW);
  displaySPI.begin(10, -1, 11, 9);
  display.begin(20000000);
  display.setRotation(0);
  display.fillScreen(GC9A01A_BLACK);
  digitalWrite(40, HIGH);
  if (!strip.getBuffer()) {
    display.setTextColor(GC9A01A_RED); display.setTextSize(2);
    display.setCursor(35, 110); display.print("RAM error");
    while (true) delay(1000);
  }
  rotation.startedAt = millis();
  drawScreen(makeScreen(sharedState, millis(), false), millis());
  BLEDevice::init("BikeStem");
  Serial.printf("StemScreen ride v2: core=%s address=%s\n",
    ESP_ARDUINO_VERSION_STR, BLEDevice::getAddress().toString().c_str());
  auto* server = BLEDevice::createServer();
  server->setCallbacks(&serverEvents);
#if defined(CONFIG_BLUEDROID_ENABLED)
  BLEDevice::setCustomGattsHandler(receiverGattEvent);
#endif
  auto* service = server->createService(STEM_SERVICE);
  auto* rx = service->createCharacteristic(STEM_RX, BLECharacteristic::PROPERTY_WRITE);
  rx->setCallbacks(&writeEvents);
  service->start();
  auto* advertising = BLEDevice::getAdvertising();
  advertising->addServiceUUID(STEM_SERVICE);
  advertising->setScanResponse(true);
  BLEAdvertisementData response;
  response.setName("BikeStem");
  advertising->setScanResponseData(response);
  advertising->start();
  Serial.println("BikeStem ready: waiting for the Garmin data field.");
}
void loop() {
  static uint32_t lastDraw = 0, loggedPackets = 0, advertiseAt = 0;
  static uint32_t lastHealth = 0, loggedConnects = 0, loggedDisconnects = 0;
  static uint32_t loggedRejected = 0;
  static bool restartPending = false;
  static uint16_t lastRing = 0xf800;
  static uint32_t lastDrawDuration = 0;
  ReceiverState state;
  portENTER_CRITICAL(&stateLock);
  state = sharedState;
  sharedState.advertiseAgain = false;
  portEXIT_CRITICAL(&stateLock);
  const uint32_t now = millis();
  if (batterySampler.due(now) &&
      batterySampler.add(now, analogReadMilliVolts(STEM_BATTERY_PIN), battery)) {
    Serial.printf("BAT t=%lu adc_mV=%lu battery_mV=%lu approx_pct=%u quarters=%u valid=%u power=unknown\n",
      (unsigned long)now, (unsigned long)battery.adcMv,
      (unsigned long)battery.millivolts, unsigned(battery.percent),
      unsigned(battery.quarters), unsigned(battery.valid));
  }
  // All logging remains in loop(), outside the BLE callback critical sections.
  if (uint32_t(now-lastHealth) >= 5000 || state.connects != loggedConnects ||
      state.disconnects != loggedDisconnects || state.rejected != loggedRejected) {
    Serial.printf("BLE t=%lu connected=%u connects=%lu disconnects=%lu rawConnects=%lu rawDisconnects=%lu writes=%lu accepted=%lu rejected=%lu malformed=%lu whileDisconnected=%lu lastLen=%u\n",
      (unsigned long)now, unsigned(state.connected), (unsigned long)state.connects,
      (unsigned long)state.disconnects, (unsigned long)state.rawConnects,
      (unsigned long)state.rawDisconnects, (unsigned long)state.writes,
      (unsigned long)state.packets, (unsigned long)state.rejected,
      (unsigned long)state.malformed, (unsigned long)state.whileDisconnected,
      unsigned(state.lastWriteLength));
    lastHealth = now; loggedConnects = state.connects;
    loggedDisconnects = state.disconnects; loggedRejected = state.rejected;
  }
  if (state.advertiseAgain) { restartPending = true; advertiseAt = now; }
  if (state.connected) restartPending = false;
  if (restartPending && uint32_t(now-advertiseAt) >= 250) {
    BLEDevice::startAdvertising(); restartPending = false;
    Serial.println("BLE advertising restart requested");
  }
  if (state.packets != loggedPackets) {
    Serial.printf("RX ride=%lus state=%u flags=%u local=%04u-%02u-%02u %02u:%02u:%02u packets=%lu rejected=%lu\n",
      (unsigned long)state.packet.durationSeconds, unsigned(state.packet.status), unsigned(state.packet.flags),
      unsigned(state.packet.year), unsigned(state.packet.month), unsigned(state.packet.day),
      unsigned(state.packet.hour), unsigned(state.packet.minute), unsigned(state.packet.second),
      (unsigned long)state.packets, (unsigned long)state.rejected);
    loggedPackets = state.packets;
  }
  rotation.update(now);
  const auto screen = makeScreen(state, now, rotation.ridePage);
  const uint32_t duration = displayedDuration(state, now);
  if (uint32_t(now-lastDraw) >= 250 || screen.ring != lastRing ||
      (rotation.ridePage && duration != lastDrawDuration)) {
    lastDraw = now;
    lastRing = screen.ring;
    lastDrawDuration = duration;
    drawScreen(screen, now);
  }
  delay(5);
}

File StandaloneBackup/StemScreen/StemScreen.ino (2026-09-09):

/* Bike Stem Computer: standalone prototype 02.
   Waveshare ESP32-S3-LCD-1.28 NON-TOUCH; same wiring/libraries as Hello.
   Short BOOT press: start/pause. Hold BOOT 2 seconds: clear and pause.
   Pages rotate every 30 seconds; a button action shows Ride Time immediately.
   Build time is approximate. See README for setting accurate time over USB.
*/
#include <Arduino.h>
#include <SPI.h>
#include <Adafruit_GFX.h>
#include <Adafruit_GC9A01A.h>
#include <esp_timer.h>
#include <sys/time.h>
#include <time.h>
#include "RideLogic.h"

#if !defined(CONFIG_IDF_TARGET_ESP32S3)
#error "Choose Tools > Board > esp32 > ESP32S3 Dev Module."
#endif

constexpr int LCD_SCK = 10, LCD_MOSI = 11, LCD_CS = 9;
constexpr int LCD_DC = 8, LCD_RST = 12, LCD_BL = 40, RIDE_BUTTON_PIN = 0;
constexpr uint64_t SCREEN_INTERVAL_MS = 10000;
constexpr uint8_t DISPLAY_ROTATION = 0;
static_assert(SCREEN_INTERVAL_MS > 0, "Screen interval must be greater than zero.");
// UK time including the current GMT/BST switching rule.
// The compiler timestamp below is interpreted as UK local time.
constexpr char TIME_ZONE[] = "GMT0BST,M3.5.0/1,M10.5.0/2";

SPIClass displaySPI(HSPI);
Adafruit_GC9A01A display(&displaySPI, LCD_DC, LCD_CS, LCD_RST);
// Compose a complete image in RAM, then transfer it to avoid clearing flicker.
GFXcanvas16 canvas(240, 240);
RideTimer ride;
RideButton button;
bool timerPage = false, forceRedraw = true, clockSynced = false;
uint64_t pageStartedMs = 0;
int64_t lastRenderedValue = -1;
char inputLine[48];
size_t inputLength = 0;
bool discardLine = false;

uint64_t monotonicMs() {
  return static_cast<uint64_t>(esp_timer_get_time()) / 1000;
}

void centredText(const char *text, int16_t y, uint8_t size, uint16_t colour) {
  canvas.setTextSize(size);
  canvas.setTextColor(colour);
  int16_t x, top;
  uint16_t w, h;
  canvas.getTextBounds(text, 0, y, &x, &top, &w, &h);
  canvas.setCursor((240 - w) / 2 - x, y);
  canvas.print(text);
}

bool setClock(int64_t epoch) {
  struct timeval tv = {};
  tv.tv_sec = static_cast<time_t>(epoch);
  return settimeofday(&tv, nullptr) == 0;
}

void setClockFromBuild() {
  // These macros are filled by the compiler on the user's Mac.
  char month[4];
  int day, year, hour, minute, second;
  if (sscanf(__DATE__, "%3s %d %d", month, &day, &year) != 3 ||
      sscanf(__TIME__, "%d:%d:%d", &hour, &minute, &second) != 3) return;
  const char *months = "JanFebMarAprMayJunJulAugSepOctNovDec";
  const char *found = strstr(months, month);
  if (!found) return;
  struct tm tm = {};
  tm.tm_year = year - 1900;
  tm.tm_mon = (found - months) / 3;
  tm.tm_mday = day;
  tm.tm_hour = hour;
  tm.tm_min = minute;
  tm.tm_sec = second;
  tm.tm_isdst = -1;
  const time_t epoch = mktime(&tm);
  if (epoch > 0) setClock(epoch);
  // Never describe a build timestamp as a live time sync.
  clockSynced = false;
}

void printStatus() {
  time_t epoch = time(nullptr);
  struct tm local;
  localtime_r(&epoch, &local);
  char wall[40], elapsed[16];
  strftime(wall, sizeof(wall), "%Y-%m-%d %H:%M:%S %Z", &local);
  formatRideTime(ride.elapsedMs(monotonicMs()), elapsed, sizeof(elapsed));
  Serial.printf("Clock: %s [%s] | Ride: %s [%s]\n", wall,
                clockSynced ? "USB set" : "approx build time", elapsed,
                ride.running ? "running" : "paused");
}

void handleLine() {
  inputLine[inputLength] = '\0';
  if (inputLength == 0) return;
  if (strcmp(inputLine, "STATUS") == 0) { printStatus(); return; }
  int64_t epoch;
  if (parseTimeCommand(inputLine, epoch) && setClock(epoch)) {
    clockSynced = true;
    forceRedraw = true;
    Serial.println("OK: clock set from USB. Ride timer unchanged.");
    printStatus();
  } else {
    Serial.println("Use TIME <Unix seconds, 2024-2099>, or STATUS. End with newline.");
  }
}

void pollSerial() {
  // Bound each pass so incoming serial data cannot starve the button.
  for (unsigned n = 0; n < 64 && Serial.available(); ++n) {
    const char c = static_cast<char>(Serial.read());
    if (c == '\r' || c == '\n') {
      if (discardLine) Serial.println("ERROR: command too long; discarded.");
      else handleLine();
      inputLength = 0;
      discardLine = false;
    } else if (!discardLine) {
      if (inputLength + 1 < sizeof(inputLine)) inputLine[inputLength++] = c;
      else discardLine = true;
    }
  }
}

void drawFrame(uint64_t now) {
  canvas.fillScreen(GC9A01A_BLACK);
  canvas.setTextWrap(false);
  const uint16_t accent = timerPage ? (ride.running ? GC9A01A_GREEN : GC9A01A_ORANGE)
                                    : GC9A01A_CYAN;
  canvas.drawCircle(120, 120, 114, accent);
  if (timerPage) {
    centredText("Ride Time", 54, 2, GC9A01A_WHITE);
    char elapsed[16];
    formatRideTime(ride.elapsedMs(now), elapsed, sizeof(elapsed));
    centredText(elapsed, 105, 4, GC9A01A_WHITE);
    centredText(ride.running ? "RUNNING" : "PAUSED", 153, 2, accent);
    centredText("Tap: start / pause", 181, 1, GC9A01A_WHITE);
    centredText("Hold 2s: reset", 194, 1, GC9A01A_WHITE);
  } else {
    time_t epoch = time(nullptr);
    struct tm local;
    localtime_r(&epoch, &local);
    char clock[8], date[24], zone[12];
    strftime(clock, sizeof(clock), "%H:%M", &local);
    strftime(date, sizeof(date), "%a %d %b", &local);
    strftime(zone, sizeof(zone), "%Z", &local);
    centredText("CLOCK", 45, 2, GC9A01A_WHITE);
    centredText(zone, 70, 1, accent);
    centredText(clock, 94, 6, GC9A01A_WHITE);
    centredText(date, 153, 2, accent);
    centredText(clockSynced ? "Time set from Mac" : "Approx time - set via USB",
                177, 1, clockSynced ? GC9A01A_WHITE : GC9A01A_ORANGE);
    centredText(ride.running ? "Tap: pause ride" : "Tap: start ride", 194, 1,
                GC9A01A_WHITE);
  }
  canvas.drawCircle(111, 215, 3, GC9A01A_DARKGREY);
  canvas.drawCircle(129, 215, 3, GC9A01A_DARKGREY);
  canvas.fillCircle(timerPage ? 129 : 111, 215, 3, accent);
  display.drawRGBBitmap(0, 0, canvas.getBuffer(), 240, 240);
}
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

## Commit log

2026-09-17 First version connecting the stem screen to a Garmin device
2026-09-18 Add first case design
    [01_Bottom_shell.stl, 02_Top_shell_and_bezel.stl, 03_Removable_electronics_carrier.stl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]
2026-09-22 Added battery status indicator
